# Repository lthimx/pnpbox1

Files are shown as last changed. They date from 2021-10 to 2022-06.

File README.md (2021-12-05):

<p align="center">
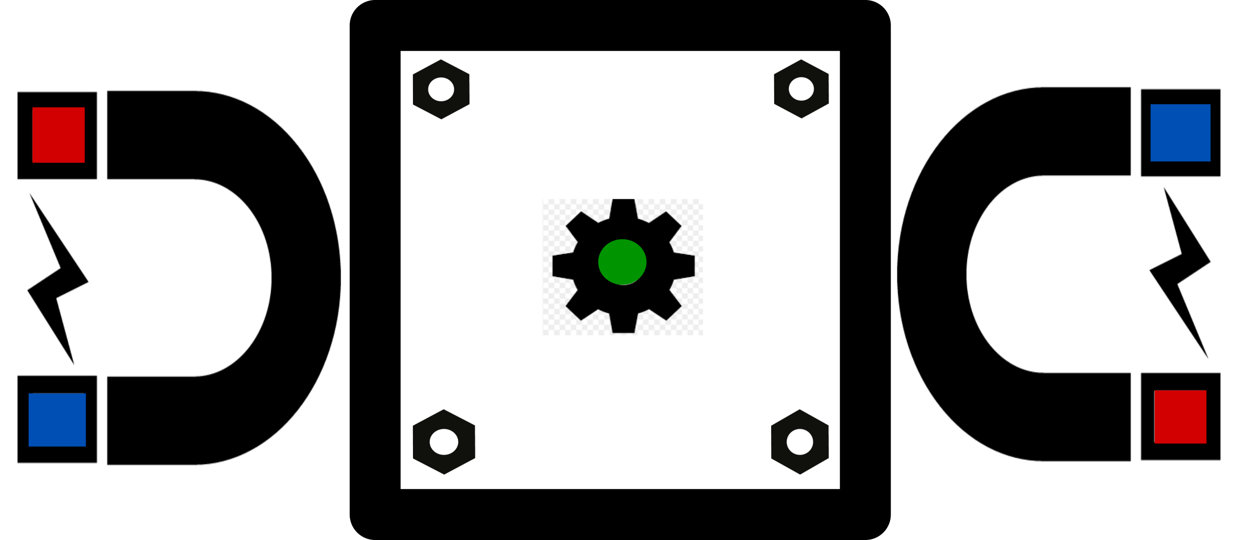
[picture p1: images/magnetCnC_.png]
MagnetCnC 3 logo
 
</p>
<h1 align="center">MagnetCnC 3</h1>

This is a prototype for pick and place, smd soldering but also laser cutting/engraving.
The head and the moving arm of the prototype will be design to be modular and magnetic (No screwing is neeeded to change/upgrade the head or arm).

## Visual overview
This is a visual overview of what the prototype does... for the moment, because it will does more "usecool" things like soldering and laser engraving or cutting.

pnpbox1

## Global view of the prototype

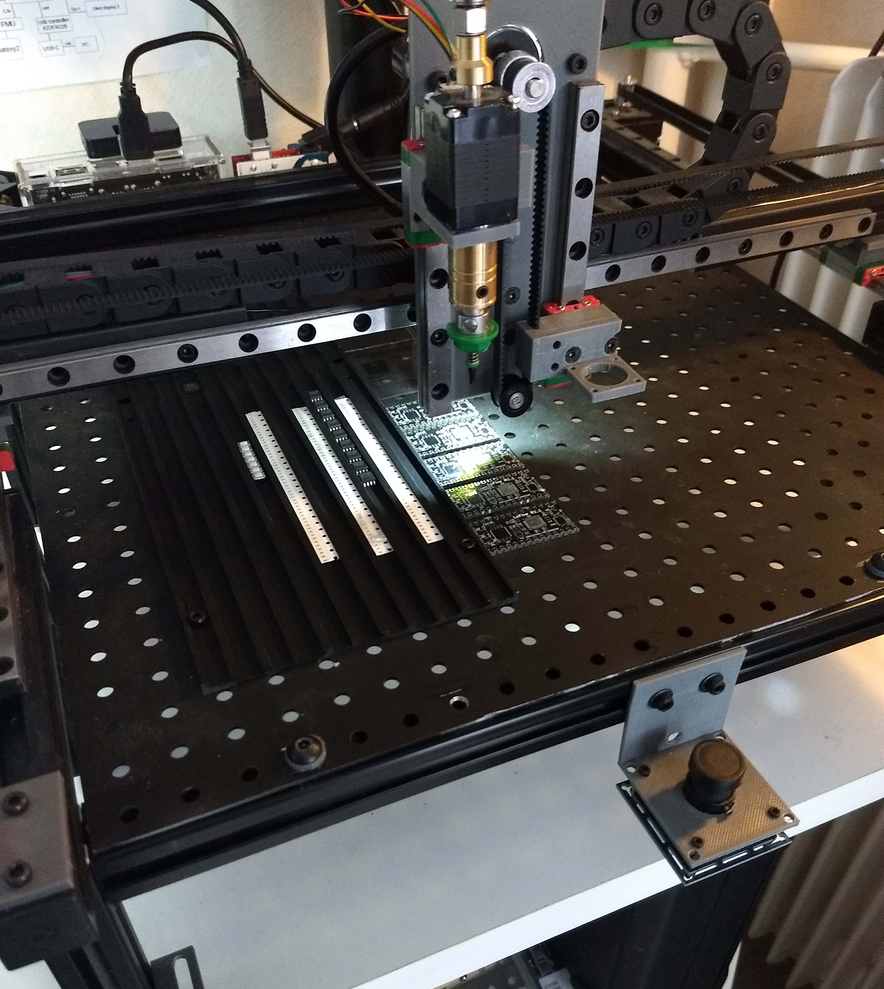
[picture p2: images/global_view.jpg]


## Buttons
This is a view of two buttons for reset and unlock operations but it can be re-configured for others actions.

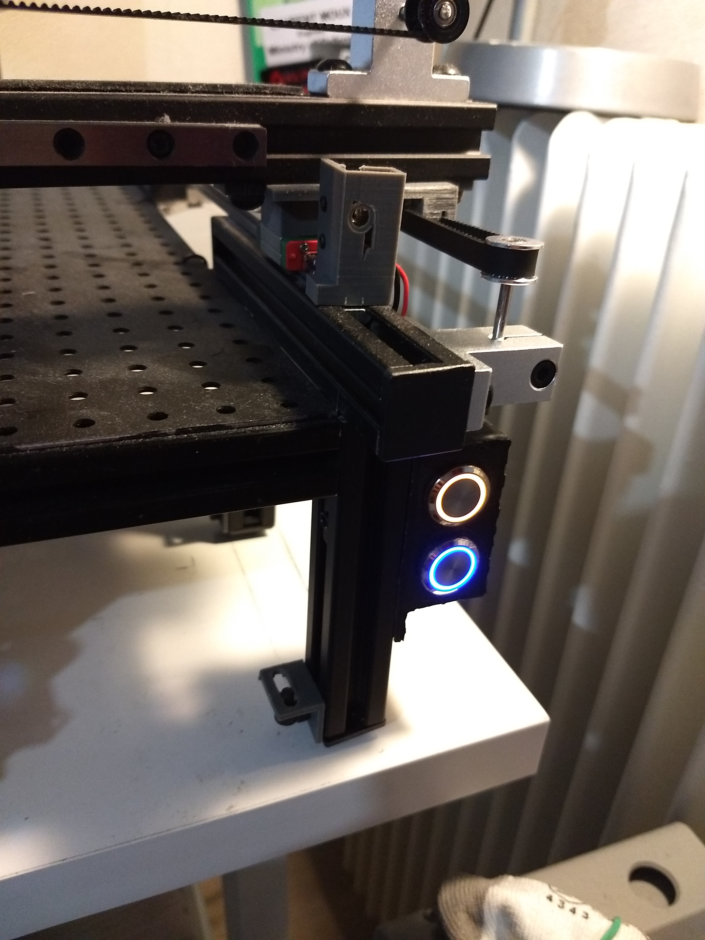
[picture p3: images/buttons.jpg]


## Pnpbox1 
This is an overview of the prototype box which contains all the mains components, the pump too ! .

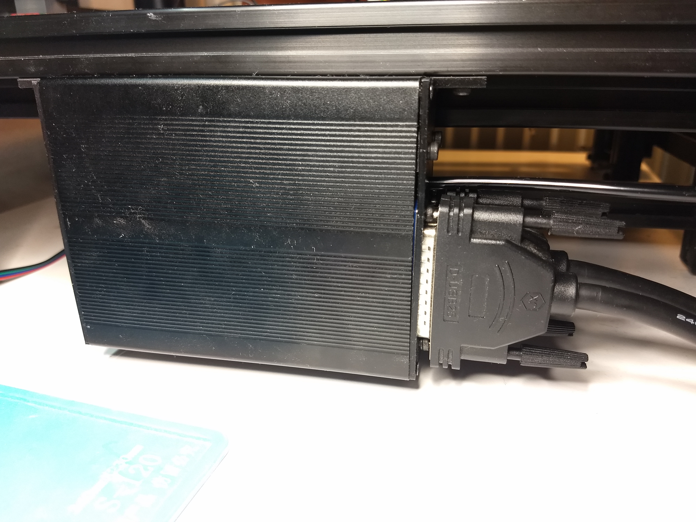
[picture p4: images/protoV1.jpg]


## DB25 pinout
This is the pinout of the two DB25 connectors on the Pnpbox
<p align="center">
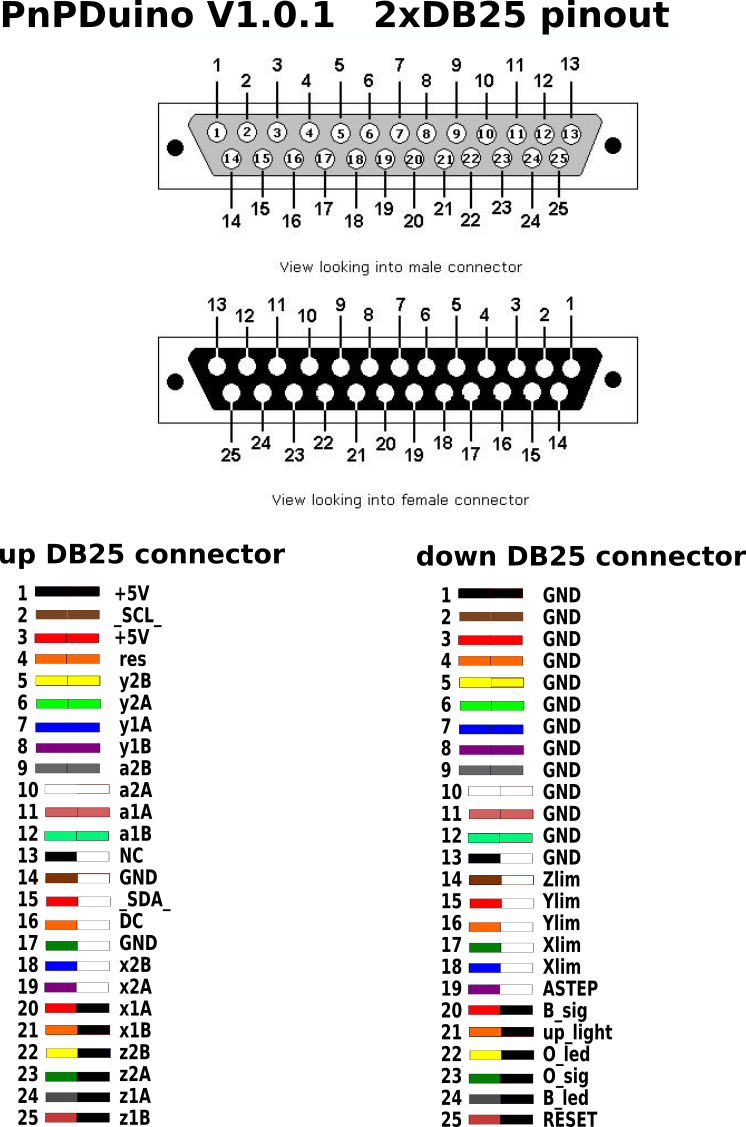
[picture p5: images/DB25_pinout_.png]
DB25 pinout
  
</p>

## Inside the pnpboxV1.0.1 prototype: Global view
<p align="center">
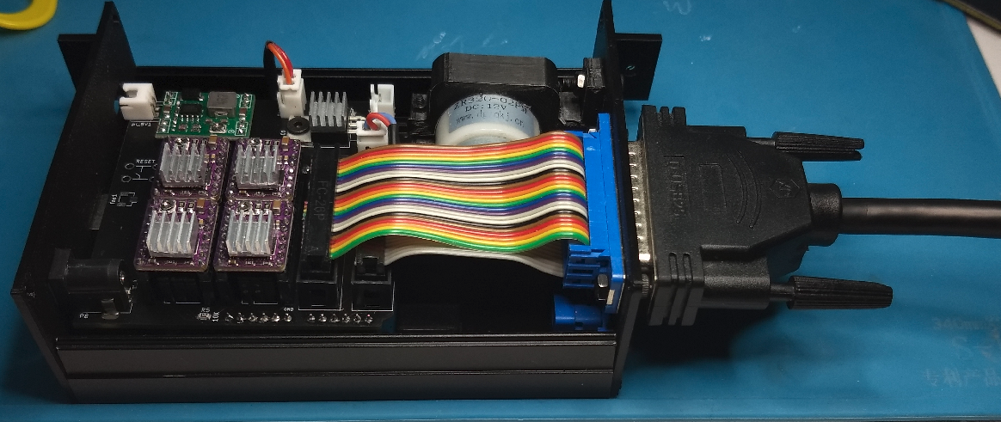
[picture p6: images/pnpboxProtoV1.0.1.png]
pnpBoxProtoV1.0.1
  
</p>

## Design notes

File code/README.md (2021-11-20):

# Programming
Here are codes for the machine movements management.
Arduino program will be adapted for the severals needs of the prototype then it will be ported on hifive rev b RISC-V board.

In order to understand how to program a stepper motor, here is a useful link from [Makerguides](https://www.makerguides.com/a4988-stepp$er-motor-driver-arduino-tutorial/)

## Zephyr OS
[Zephyr OS](https://zephyrproject.org/) will be used for the hifive rev b board because it is based on a small-footprint kernel designed for resource-constrained and embedded systems. Moreover it is open source and it is a project supported by the zephyr community.[Here](https://docs.zephyrproject.org/latest/getting_started/index.html) is the Zephyr getting started guide.

## List of main.c functions to be ported on hifive rev b

|Functions|Description|status|
|:---: | :---: |:---:|
|serial_init()| Setup serial baud rate and interrupt| OK| 
|setting_init()| Load grbl settings from flash memory| in progress|
|stepper_init()| Configure stepper pins and interrupt timers|in progress|
|system_init()| Configure pinout pins and pin-change interrupt|in progress|
|sei()| Enable interrupts| in progress|
|serial_reset_read_buffer()| Clear serial read buffer| in progress|
|gc_init()| set g-code parser to default state| in progress|
|pump_init()| init pump| in progress|
|rst_led_init()| init reset button | in progress |
|limits_init()| init limit pin| in progress|
|...|...|...|

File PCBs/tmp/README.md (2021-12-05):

# DuinoPnP v1
Here are the kicad files for the prototype shield for the machine, it is designed with the arduino-uno form factor, i call it the "duinoPnP"

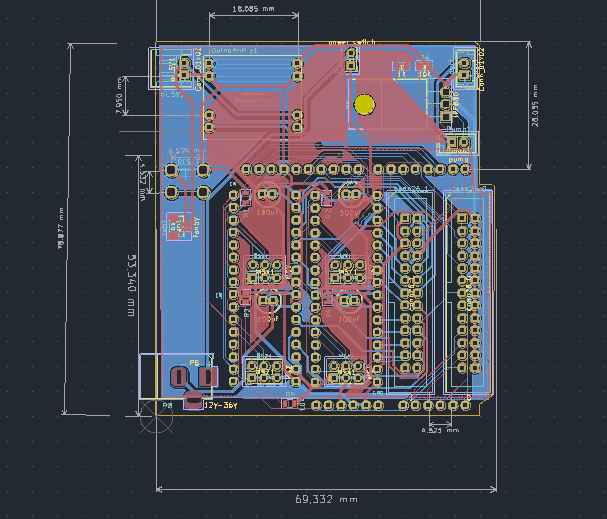
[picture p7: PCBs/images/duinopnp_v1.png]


## v1.0.1 3D viewer

Global 3D view of V1.0.1 PCB
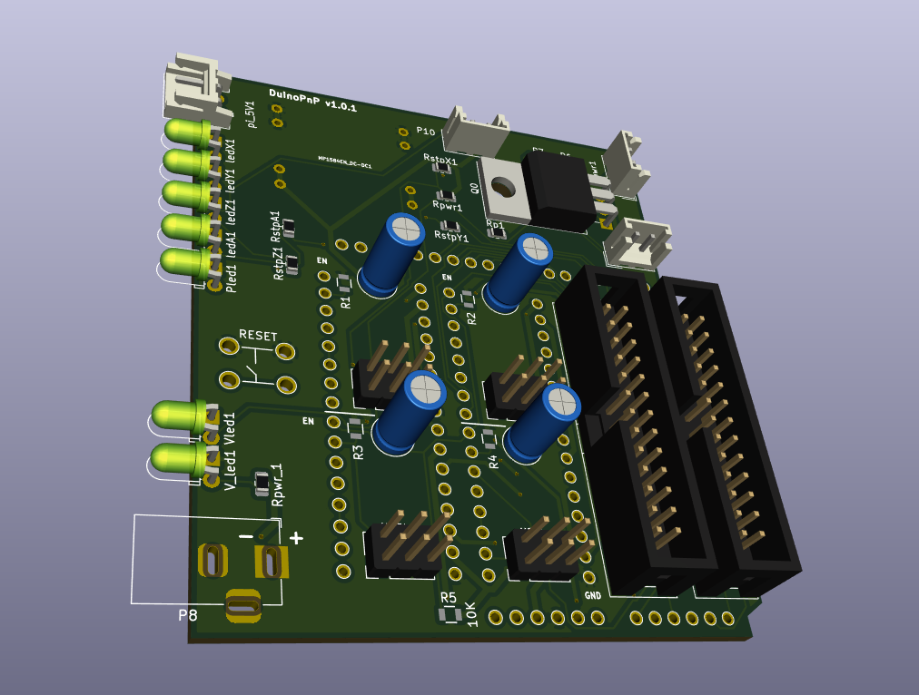
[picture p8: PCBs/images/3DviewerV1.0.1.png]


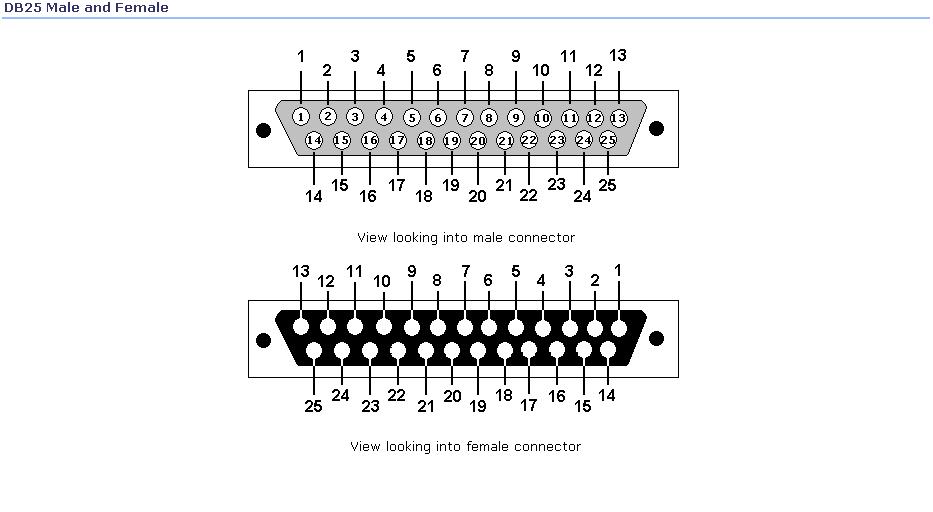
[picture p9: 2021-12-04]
images/Db25_pinout.jpg

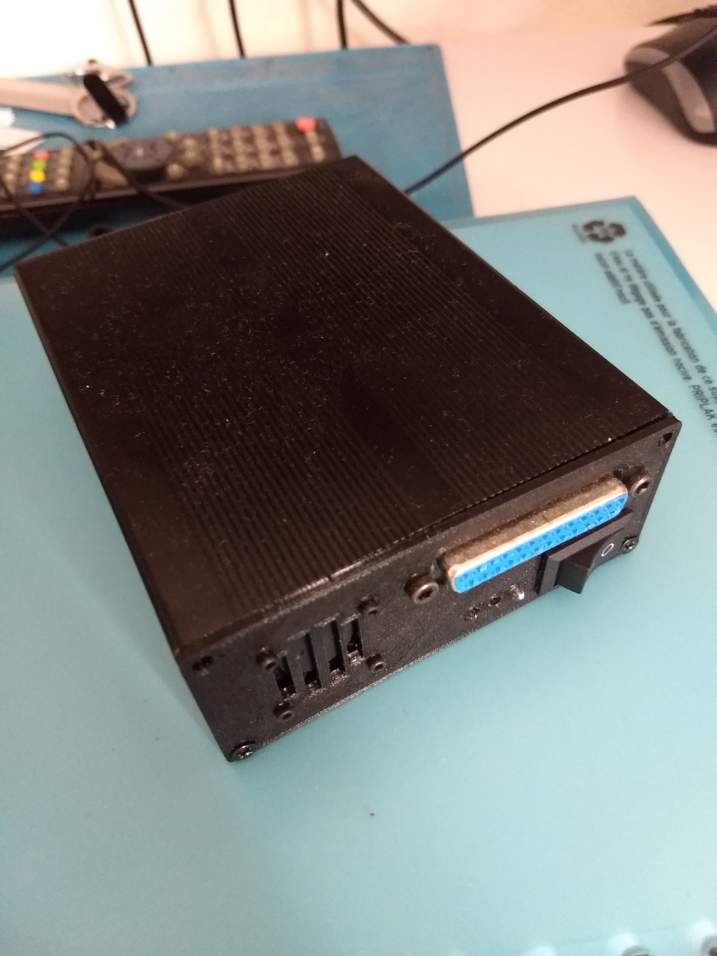
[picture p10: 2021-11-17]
images/pnpbox1.jpg

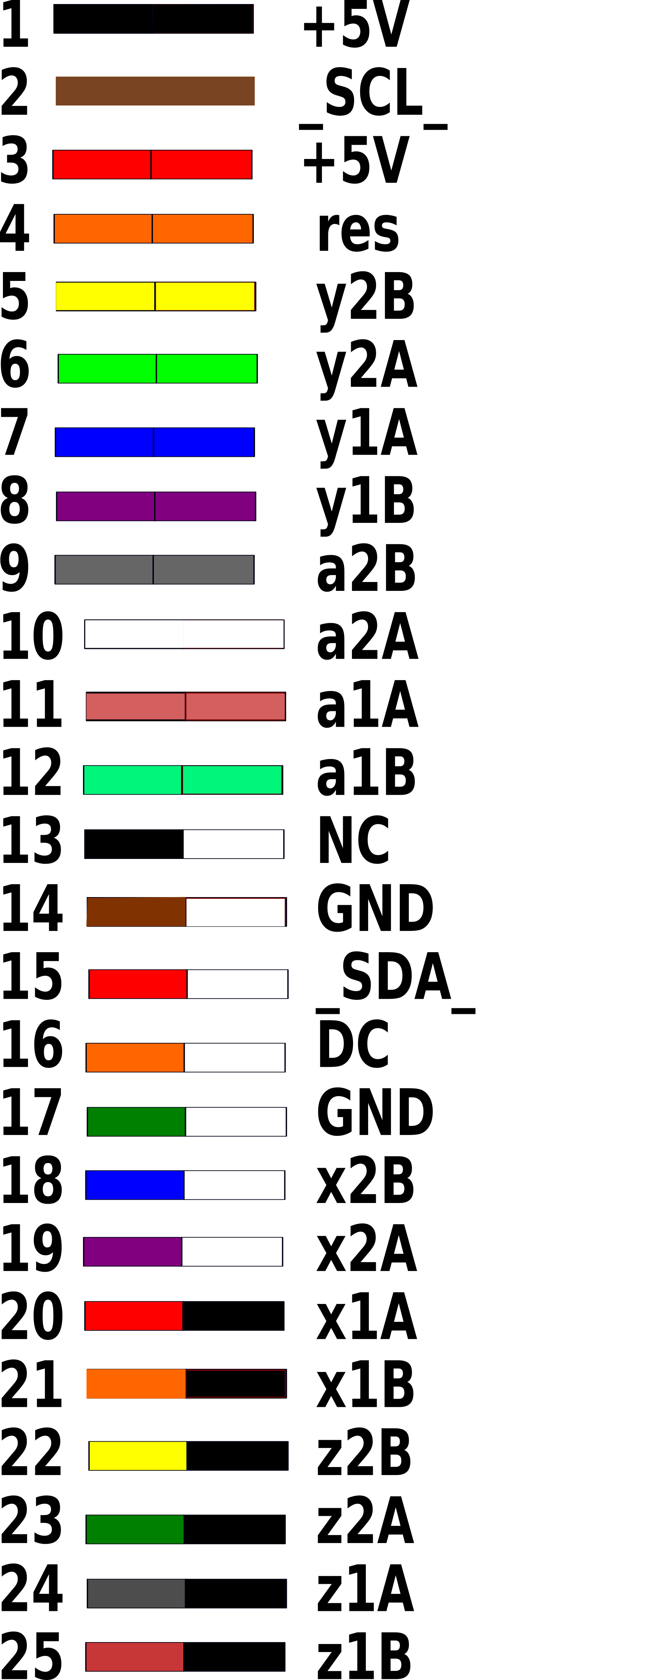
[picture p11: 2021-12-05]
images/text990.png

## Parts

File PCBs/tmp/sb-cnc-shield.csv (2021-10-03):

Reference | Value | Footprint | Datasheet
U1 | ARDUINO_UNO_SHIELD | footprints:ARDUINO_SHIELD
U5 | A | footprints:POLOLU_STEPPER_DRIVER
U3 | Y | footprints:POLOLU_STEPPER_DRIVER
U2 | X | footprints:POLOLU_STEPPER_DRIVER
U4 | Z | footprints:POLOLU_STEPPER_DRIVER
P1 | XMOT | Pin_Headers:Pin_Header_Straight_2x04
P2 | YMOT | Pin_Headers:Pin_Header_Straight_2x04
P3 | ZMOT | Pin_Headers:Pin_Header_Straight_2x04
P4 | AMOT | Pin_Headers:Pin_Header_Straight_2x04
JP1 | Jumper_NO_Small | footprints:Pin_100mil_Header_Straight_1x02
JP2 | Jumper_NO_Small | footprints:Pin_100mil_Header_Straight_1x02
JP3 | Jumper_NO_Small | footprints:Pin_100mil_Header_Straight_1x02
R1 | 100K | Resistors_SMD:R_0805
R2 | 100K | Resistors_SMD:R_0805
JP4 | Jumper_NO_Small | footprints:Pin_100mil_Header_Straight_1x02
JP5 | Jumper_NO_Small | footprints:Pin_100mil_Header_Straight_1x02
JP6 | Jumper_NO_Small | footprints:Pin_100mil_Header_Straight_1x02
JP7 | Jumper_NO_Small | footprints:Pin_100mil_Header_Straight_1x02
JP8 | Jumper_NO_Small | footprints:Pin_100mil_Header_Straight_1x02
JP9 | Jumper_NO_Small | footprints:Pin_100mil_Header_Straight_1x02
R3 | 100K | Resistors_SMD:R_0805
JP10 | Jumper_NO_Small | footprints:Pin_100mil_Header_Straight_1x02
JP11 | Jumper_NO_Small | footprints:Pin_100mil_Header_Straight_1x02
JP12 | Jumper_NO_Small | footprints:Pin_100mil_Header_Straight_1x02
R4 | 100K | Resistors_SMD:R_0805
C1 | 100uF | Capacitors_SMD:c_elec_6.3x7.7
C2 | 100uF | Capacitors_SMD:c_elec_6.3x7.7
C3 | 100uF | Capacitors_SMD:c_elec_6.3x7.7
C4 | 100uF | Capacitors_SMD:c_elec_6.3x7.7
P5 | UART | Pin_Headers:Pin_Header_Straight_1x04
P6 | I2C | Pin_Headers:Pin_Header_Straight_1x04
JP13 | Z+ | footprints:Pin_100mil_Header_Straight_1x02
JP14 | Z- | footprints:Pin_100mil_Header_Straight_1x02
JP15 | Y+ | footprints:Pin_100mil_Header_Straight_1x02
JP16 | Y- | footprints:Pin_100mil_Header_Straight_1x02
JP17 | X+ | footprints:Pin_100mil_Header_Straight_1x02
JP18 | X- | footprints:Pin_100mil_Header_Straight_1x02
JP19 | SpinEn | footprints:Pin_100mil_Header_Straight_1x02
JP20 | SpinDir | footprints:Pin_100mil_Header_Straight_1x02
JP21 | CoolEn | footprints:Pin_100mil_Header_Straight_1x02
JP22 | Abort | footprints:Pin_100mil_Header_Straight_1x02
JP23 | Hold | footprints:Pin_100mil_Header_Straight_1x02
JP24 | Resume | footprints:Pin_100mil_Header_Straight_1x02
P7 | ES_SETUP | Pin_Headers:Pin_Header_Straight_1x03
SW1 | RESET | footprints:SWITCH_TACTILE_6.5_PTH
JP25 | ESTOP | footprints:Pin_100mil_Header_Straight_1x02
JP26 | EN/GND | footprints:Pin_100mil_Header_Straight_1x02
JP27 | XSTEP/DIR | footprints:Pin_100mil_Header_Straight_1x02
JP28 | YSTEP/DIR | footprints:Pin_100mil_Header_Straight_1x02
JP29 | ZSTEP/DIR | footprints:Pin_100mil_Header_Straight_1x02
JP30 | ASTEP/DIR | footprints:Pin_100mil_Header_Straight_1x02
JP31 | +5V/GND | footprints:Pin_100mil_Header_Straight_1x02
JP32 | Jumper_NO_Small | footprints:Pin_100mil_Header_Straight_1x02
JP33 | Jumper_NO_Small | footprints:Pin_100mil_Header_Straight_1x02
JP34 | Jumper_NO_Small | footprints:Pin_100mil_Header_Straight_1x02
JP35 | Jumper_NO_Small | footprints:Pin_100mil_Header_Straight_1x02
JP36 | Jumper_NO_Small | footprints:Pin_100mil_Header_Straight_1x02
JP37 | Jumper_NO_Small | footprints:Pin_100mil_Header_Straight_1x02
JP38 | Jumper_NO_Small | footprints:Pin_100mil_Header_Straight_1x02
JP39 | Jumper_NO_Small | footprints:Pin_100mil_Header_Straight_1x02
P8 | 12V-36V | footprints:CONN_01x02_PITCH_5.08mm
R5 | 10K | Resistors_SMD:R_0805

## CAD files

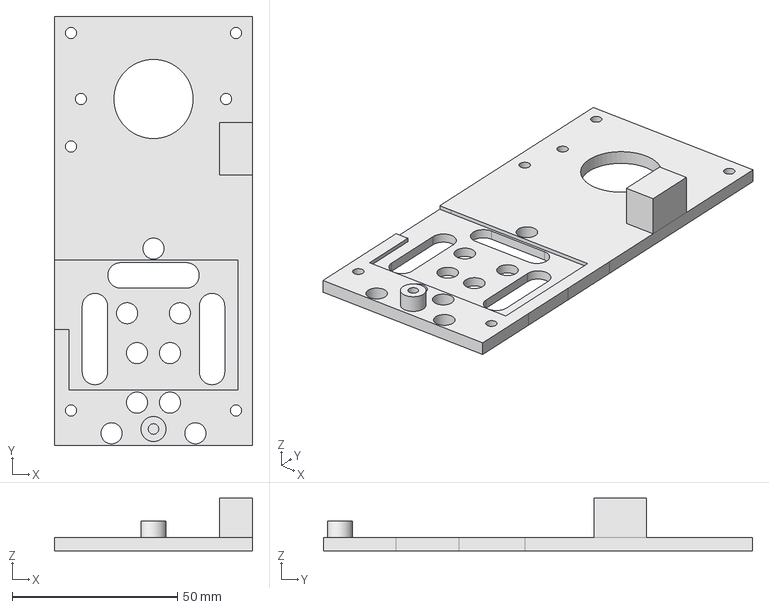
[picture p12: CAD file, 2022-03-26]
freecad/simplePnP/main_head_PnP_v1.02.FCStd
60.0 x 130.0 x 16.0 mm

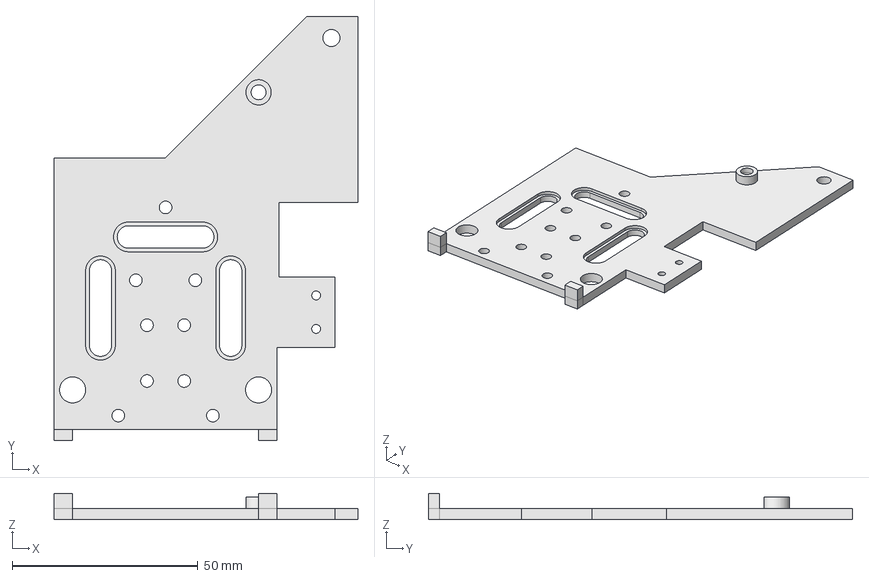
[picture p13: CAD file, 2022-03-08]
freecad/simplePnP/main_head_v1.01.FCStd
81.7 x 114.0 x 7.00 mm

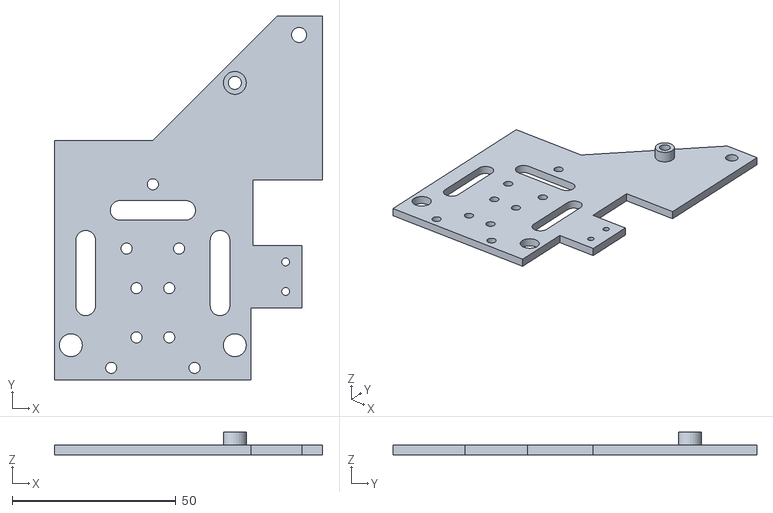
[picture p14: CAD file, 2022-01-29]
freecad/simplePnP/main_head_v1.03_with_pneumatic_cable_adapter.obj
81.7 x 111.0 x 7.00

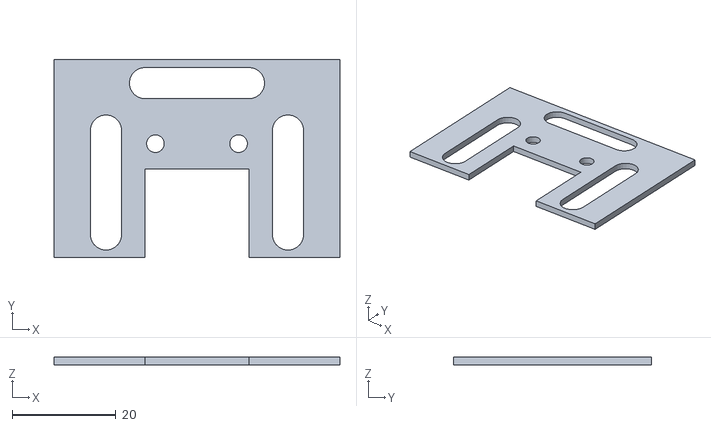
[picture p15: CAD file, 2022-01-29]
freecad/simplePnP/magnet_support_main_fixed_1.01.obj
55.0 x 38.0 x 1.50

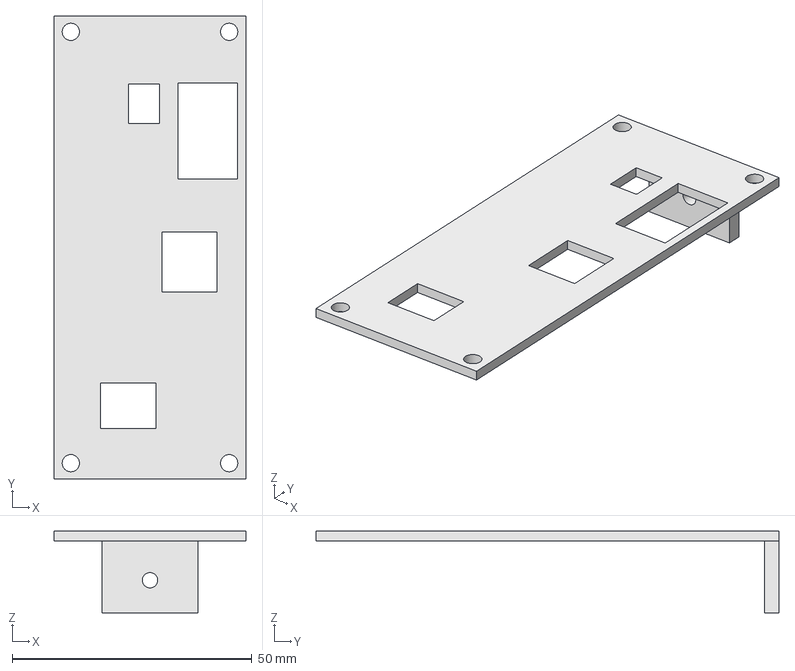
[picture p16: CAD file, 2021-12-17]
freecad/case_pnp/right_case_2.FCStd
40.0 x 96.5 x 17.0 mm

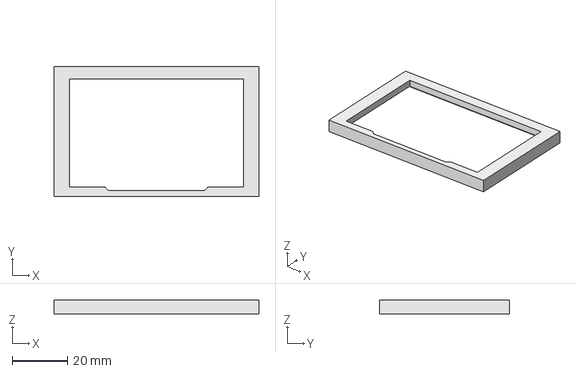
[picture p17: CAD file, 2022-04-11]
freecad/display/up_case.FCStd
74.1 x 47.0 x 5.00 mm

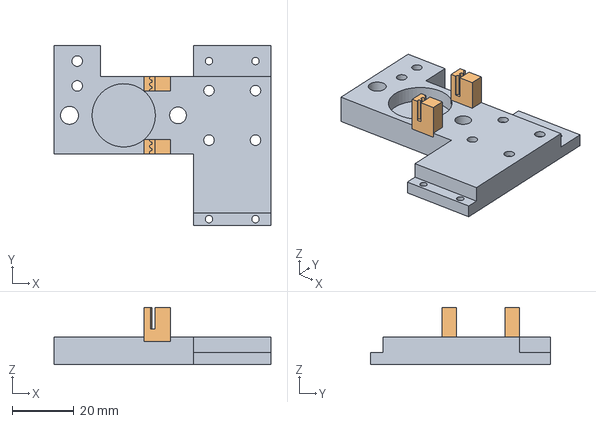
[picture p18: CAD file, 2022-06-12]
freecad/magnet_support_main_arm/down_left_magnet_arm.FCStd
70.0 x 58.0 x 18.5 mm
belt_support_left001

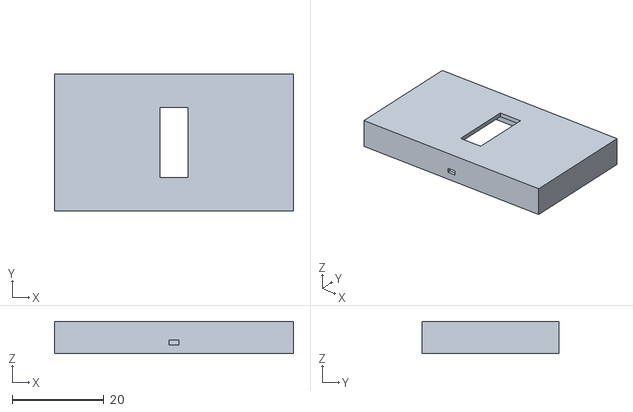
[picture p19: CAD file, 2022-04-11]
freecad/reset_button/reset_button_cache.obj
52.1 x 29.9 x 7.00

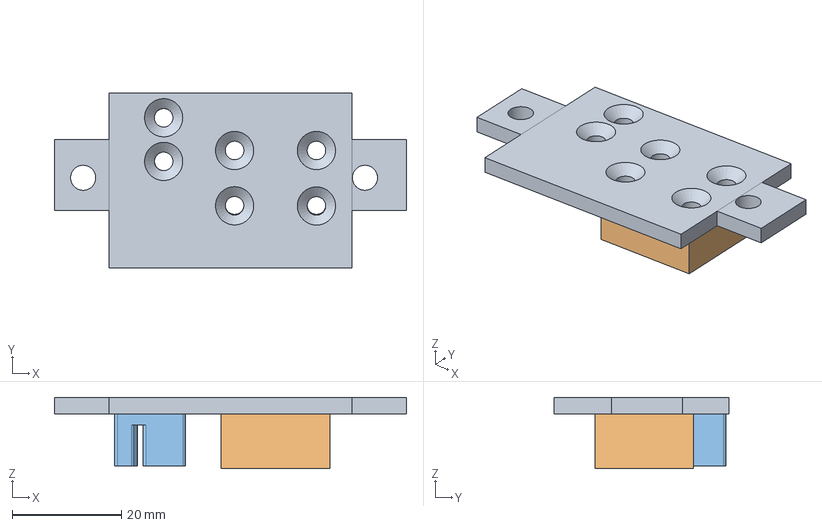
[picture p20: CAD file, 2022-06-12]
freecad/simplePnP/support_advanced_left.FCStd
64.5 x 32.0 x 13.0 mm

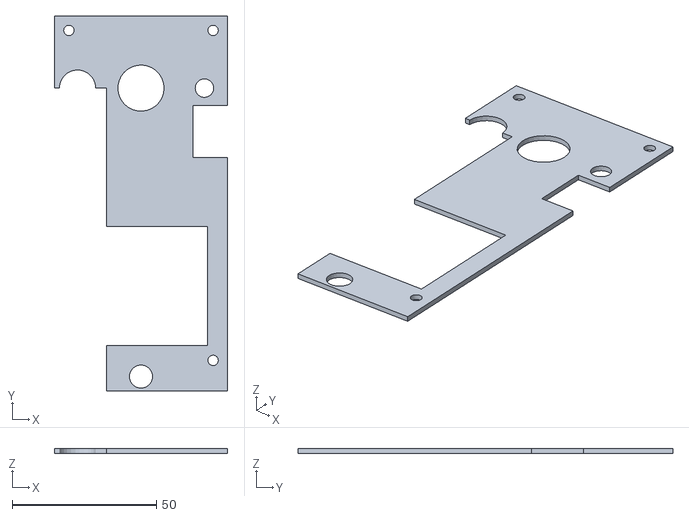
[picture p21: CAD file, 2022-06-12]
freecad/stl/head_pnp_1.stl
60.0 x 130.0 x 1.60

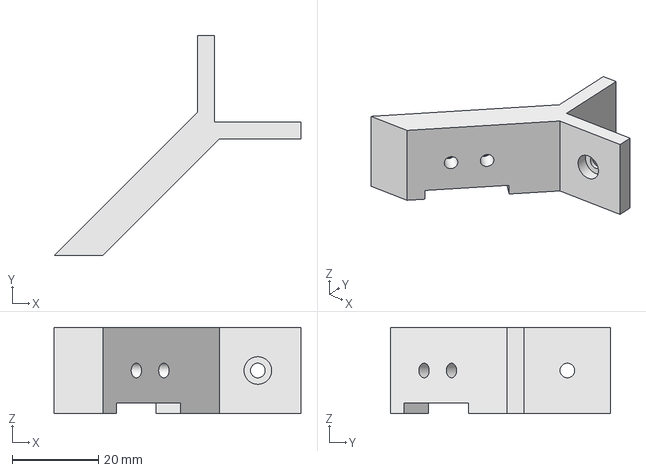
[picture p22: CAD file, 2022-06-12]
freecad/support_display/support_display.FCStd
57.2 x 51.0 x 20.0 mm

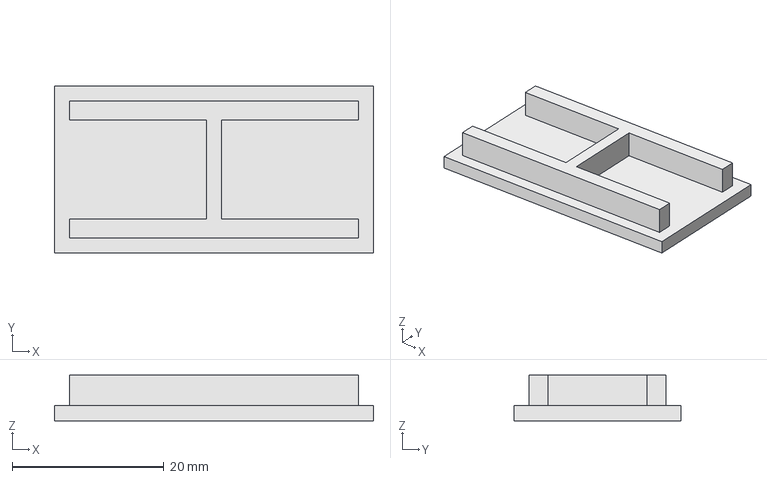
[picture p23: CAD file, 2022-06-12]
freecad/usb_cam_case/usb_down_case.FCStd
42.0 x 22.0 x 6.00 mm

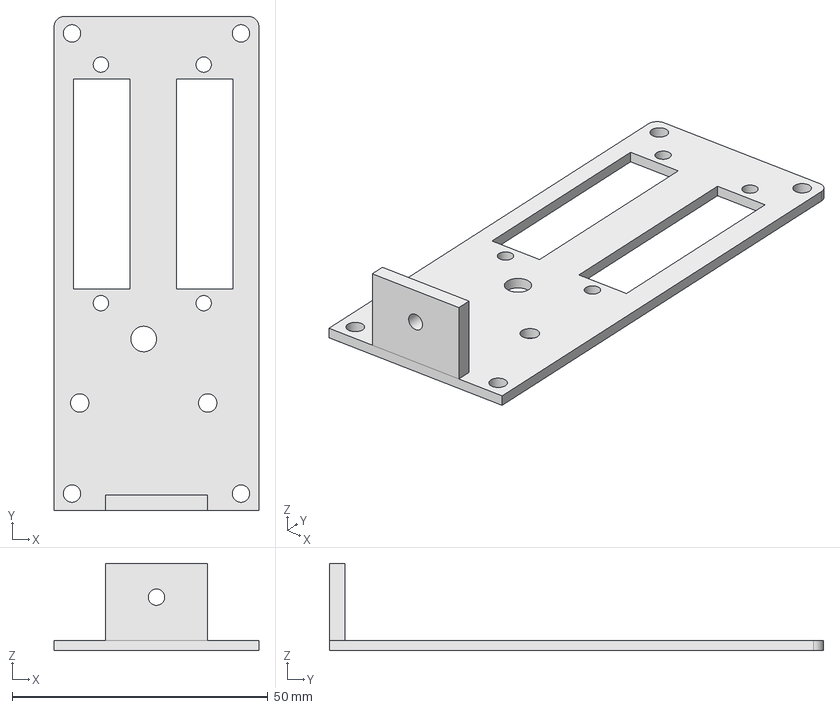
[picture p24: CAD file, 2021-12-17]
freecad/case_pnp/left_case_2.FCStd
40.0 x 96.5 x 17.0 mm

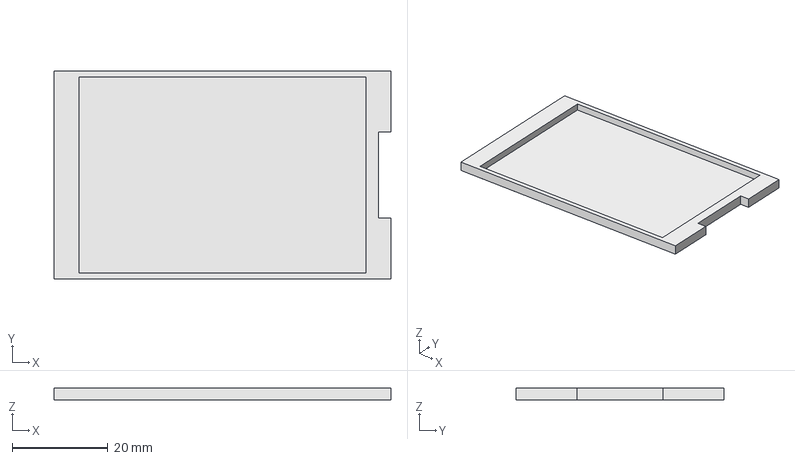
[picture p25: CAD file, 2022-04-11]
freecad/display/down_case.FCStd
70.5 x 43.6 x 2.50 mm

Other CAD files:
freecad/simplePnP/main_head_PnP_v1.01_4_tmp.FCStd
freecad/simplePnP/main_head_v1.03_with_pneumatic_cable_adapter_2.obj
freecad/magnet_support_main_arm/down_right_magnet_support_angle_arm.obj
freecad/reset_button/reset_unlock.obj
freecad/case_pnp/bute_arduino.FCStd
freecad/case_pnp/bute_arduino.obj
freecad/case_pnp/cale_arduino.obj
freecad/case_pnp/hifive_support.FCStd
freecad/case_pnp/left_case.FCStd
freecad/case_pnp/left_case_2_motore_conn.FCStd
freecad/case_pnp/pnp_case_left.obj
freecad/case_pnp/pnp_case_left_2.obj
freecad/case_pnp/pnp_case_left_motor_conn.obj
freecad/case_pnp/pnp_case_left_test.obj
freecad/case_pnp/pnp_case_right.obj
freecad/case_pnp/pnp_case_right_2.obj
freecad/case_pnp/pnp_support_hifive.obj
freecad/case_pnp/pump_support.FCStd
freecad/case_pnp/pump_supportV2.FCStd
freecad/case_pnp/right_case.FCStd
freecad/case_pnp/support_pump.obj
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

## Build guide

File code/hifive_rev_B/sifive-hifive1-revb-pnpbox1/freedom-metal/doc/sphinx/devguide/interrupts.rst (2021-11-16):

Interrupt Handlers
==================

The Interrupt Heirarchy
-----------------------

Freedom Metal conceptualizes interrupts as a heirarchy of interrupt controllers.
This heirarchy is established by the interrupt heirarchy of the target platform
itself. Presently, the interrupt heirarchy for a given platform is best documented
by the target's DeviceTree representation, which can be found in
``bsp/<target-name>/design.dts``.

In Freedom Metal, the heirarchy is a tree. The nodes of the tree consist of
``struct metal_interrupt``:

.. doxygenstruct:: metal_interrupt
   :project: metal

And the vertices of the tree consist of interrupt ``id``.

.. digraph:: int_heirarchy_graph

   cpu [label="CPU"];
   cpu_int [label="CPU Interrupt Controller", shape=box];
   timer_int [label="Timer Interrupt Controller", shape=box];
   soft_int [label="Software Interrupt Controller", shape=box];

   cpu -> cpu_int [label="ID = 0"];
   cpu_int -> timer_int [label="ID = timer_id"];
   cpu_int -> soft_int [label="ID = software_id"];

The CPU Interrupt Controller
----------------------------

The CPU interrupt controller is the top of the interrupt heirarchy. It must be
initialized before any other interrupt controllers are initialized. In example:

.. code-block:: C

   struct metal_cpu *cpu0 = metal_cpu_get(0);
   if(!cpu) {
      /* Unable to get CPU handle */
   }
   struct metal_interrupt *cpu_int = metal_cpu_interrupt_controller(cpu0);
   if(!cpu_int) {
      /* Unable to get CPU interrupt handle */
   }
   metal_interrupt_init(cpu_int);

The CPU interrupt must be enabled for the CPU to receive any interrupts, and any
enabled interrupts can be masked by disabling the CPU interrupt.

.. code-block:: C

   int rc = 0;

   /* Enable the CPU interrupt */
   rc = metal_interrupt_enable(cpu_int, 0);
   if(rc != 0) {
      /* Failed to enable the CPU interrupt */
   }

   /* Disable the CPU interrupt */
   rc = metal_interrupt_disable(cpu_int, 0);
   if(rc != 0) {
      /* Failed to disable the CPU interrupt */
   }

Interrupt Handlers
------------------

Interrupt handlers must conform to the following function signature:

.. doxygentypedef:: metal_interrupt_handler_t
   :project: metal

Therefore, an interrupt handler might look like:

.. code-block:: C

   void my_interrupt_handler(int id, void *priv_data) {
      /* Contents of handler */
   }

Registering an Interrupt Handler
--------------------------------

Interrupt handlers are registered with the interrupt controller for the interrupt
they are servicing. For example, if we want to register a CPU timer interrupt:

.. code-block:: C

   struct metal_interrupt *timer_int = metal_cpu_timer_interrupt_controller(cpu0);
   if(!timer_int) {
      /* Failed to get timer interrupt controller */
   }
   metal_interrupt_init(timer_int);

   int timer_id = metal_cpu_timer_get_interrupt_id(cpu0);

   int rc = metal_interrupt_register_handler(timer_int, timer_id, my_interrupt_handler, cpu0);
   if(rc != 0) {
      /* Failed to register interrupt handler */
   }

Additional Documentation
------------------------

Additional documentation for the interrupt handler API can be found in
:doc:`the CPU API reference </apiref/cpu>` and
:doc:`the Interrupt API reference </apiref/interrupt>`.

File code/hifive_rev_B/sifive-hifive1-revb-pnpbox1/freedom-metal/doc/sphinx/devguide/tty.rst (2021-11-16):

Standard I/O
============

Freedom Metal integrates with libc ``STDOUT`` to provide virtual terminal support.
The default ``STDOUT`` device is the first UART serial peripheral on the target.
If no UART serial peripheral is present, such as in the case of SiFive CoreIP
test harnesses, then the bytes sent to ``STDOUT`` are dropped.

Hello World
-----------

Using the virtual terminal with Freedom Metal is exactly what you might expect:

.. code-block:: C
   :linenos:

   #include <stdio.h>

   int main(void) {
      printf("Hello, world!");

      return 0;
   }

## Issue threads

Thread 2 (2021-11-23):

Test the little FS in flash with Zephyr OS on the hifive1 revb

lthimx, 2021-11-23:
Hi,
When i lunch the command "west build -p auto -b hifive1_revb samples/subsys/nvs/" in order to compile the sample, i get this first error:

error: '__device_dts_ord_DT_COMPAT_fixed_partitions_LABEL_storage_PARENT_PARENT_ORD' undeclared (first use in this function)
   81 | #define DEVICE_NAME_GET(name) _CONCAT(__device_, name)
      |                                       ^~~~~~~~~

The __device_ parameter seems to be undeclared. I'm currently trying to debug the modules and susbsys contents to solve the problem...
Any idea on where i may focus on principally ?

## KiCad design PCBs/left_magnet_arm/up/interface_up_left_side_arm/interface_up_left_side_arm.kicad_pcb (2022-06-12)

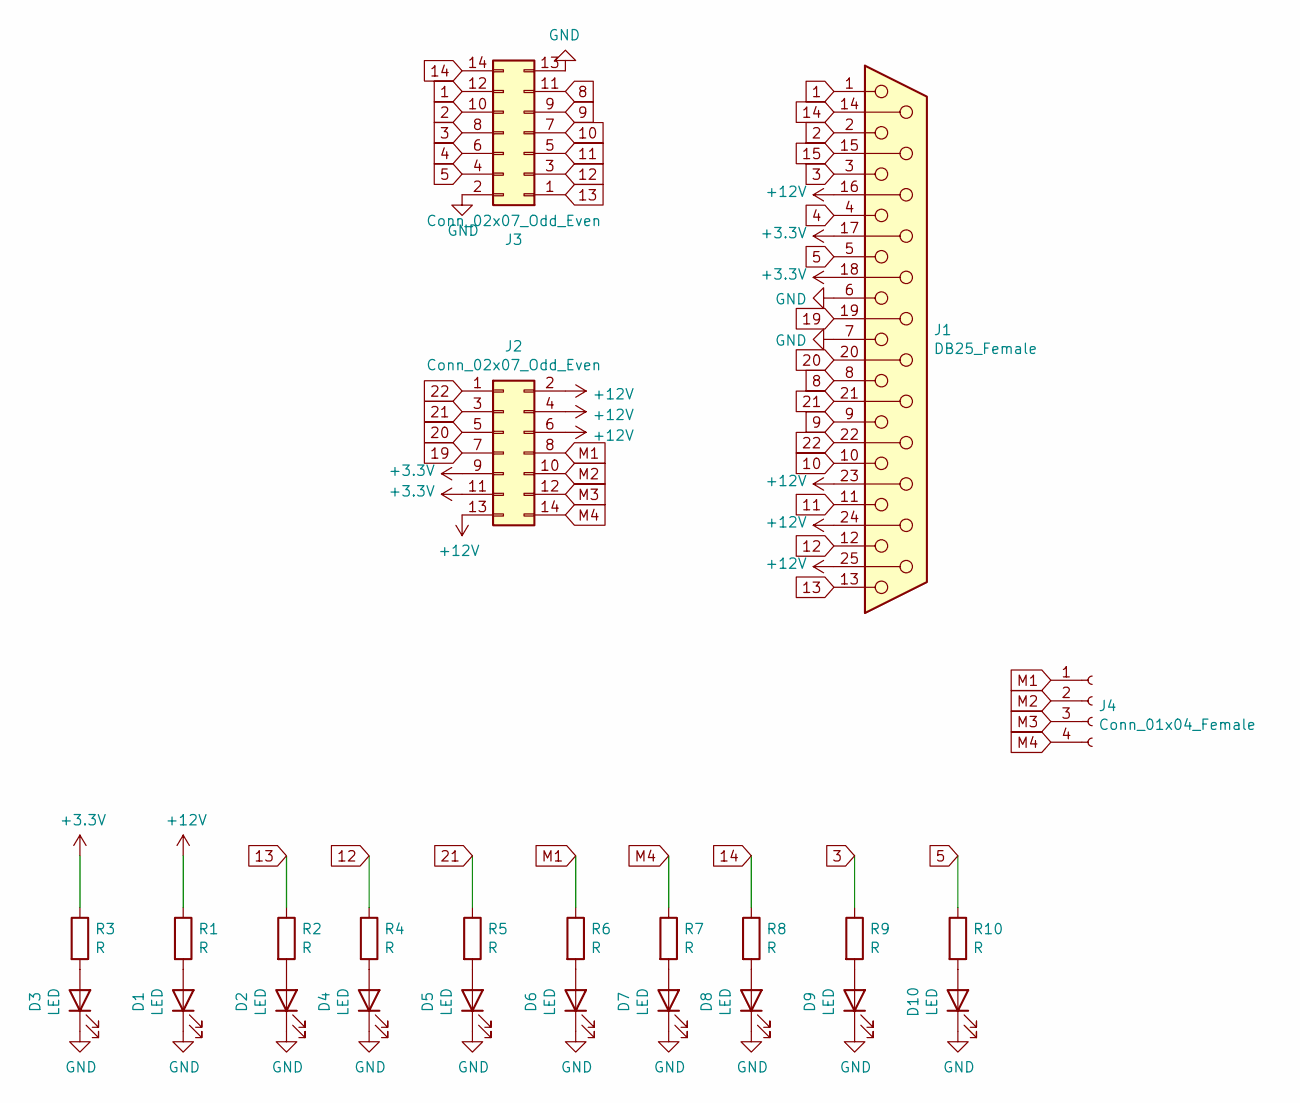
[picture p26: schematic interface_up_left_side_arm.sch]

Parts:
D1, D2, D3, D4, D5, D6, D7, D8, D9, D10: LED; LED_1206_3216Metric_Pad1.42x1.75mm_HandSolder
J1: DB25_Female; DSUB-25_Female_Vertical_P2.77x2.84mm_MountingHoles
J2, J3: Conn_02x07_Odd_Even; PinHeader_2x07_P2.54mm_Vertical
J4: Conn_01x04_Female; JST_EH_B4B-EH-A_1x04_P2.50mm_Vertical
R1, R2, R3, R4, R5, R6, R7, R8, R9, R10: R; R_0805_2012Metric

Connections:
1: J1.1, J3.12
2: J1.2, J3.10
3: J1.3, J3.8, R9.1
4: J1.4, J3.6
5: J1.5, J3.4, R10.1
8: J1.8, J3.11
9: J1.9, J3.9
10: J1.10, J3.7
11: J1.11, J3.5
12: J1.12, J3.3, R4.1
13: J1.13, J3.1, R2.1
14: J1.14, J3.14, R8.1
15: J1.15
19: J1.19, J2.7
20: J1.20, J2.5
21: J1.21, J2.3, R5.1
22: J1.22, J2.1
+3V3: J1.17, J1.18, J2.9, J2.11, R3.1
+12V: J1.16, J1.23, J1.24, J1.25, J2.2, J2.4, J2.6, J2.13, R1.1
GND: D1.1 (K), D2.1 (K), D3.1 (K), D4.1 (K), D5.1 (K), D6.1 (K), D7.1 (K), D8.1 (K), D9.1 (K), D10.1 (K), J1.6, J1.7, J3.2, J3.13
M1: J2.8, J4.1, R6.1
M2: J2.10, J4.2
M3: J2.12, J4.3
M4: J2.14, J4.4, R7.1
unnamed: D1.2 (A), R1.2
unnamed: D2.2 (A), R2.2
unnamed: D3.2 (A), R3.2
unnamed: D4.2 (A), R4.2
unnamed: D5.2 (A), R5.2
unnamed: D6.2 (A), R6.2
unnamed: D7.2 (A), R7.2
unnamed: D8.2 (A), R8.2
unnamed: D9.2 (A), R9.2
unnamed: D10.2 (A), R10.2

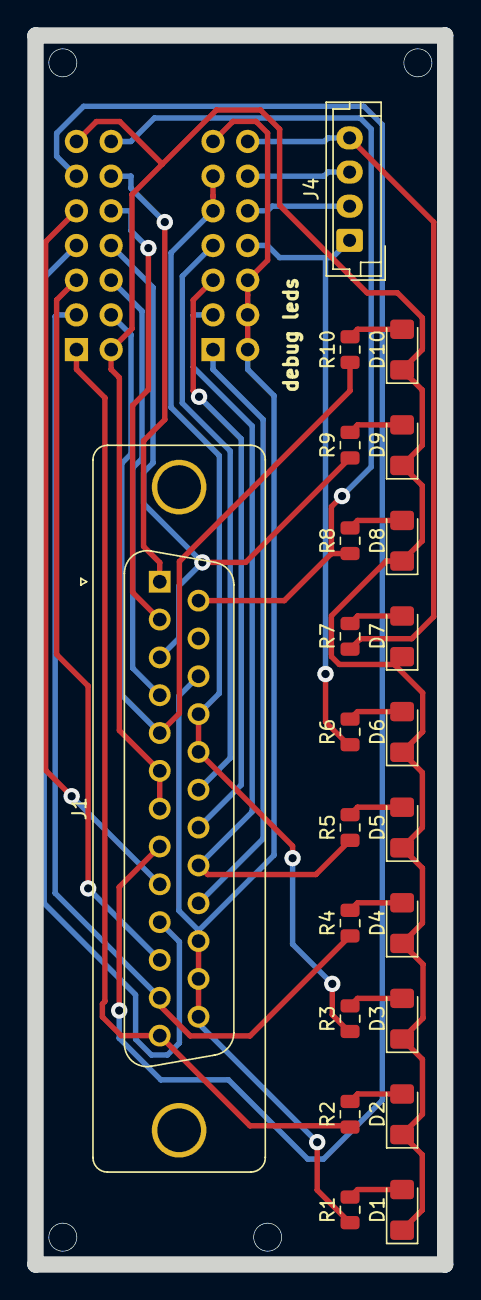
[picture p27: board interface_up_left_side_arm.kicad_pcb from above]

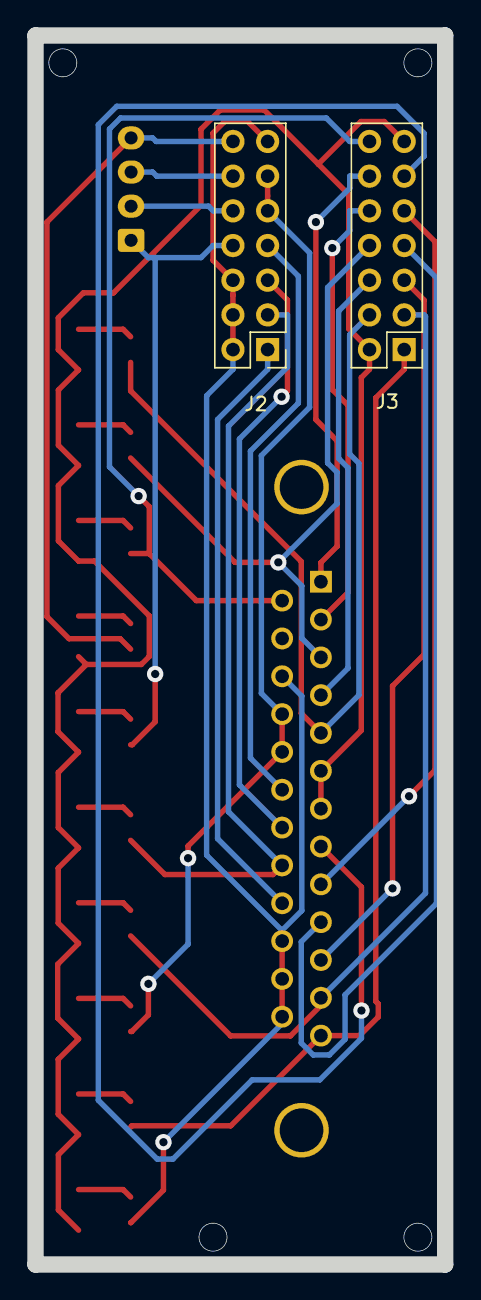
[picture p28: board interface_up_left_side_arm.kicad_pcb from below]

Board: 2 copper layers, 30.0 x 90.0 mm, 24 parts (2 on the bottom side), 33 nets.

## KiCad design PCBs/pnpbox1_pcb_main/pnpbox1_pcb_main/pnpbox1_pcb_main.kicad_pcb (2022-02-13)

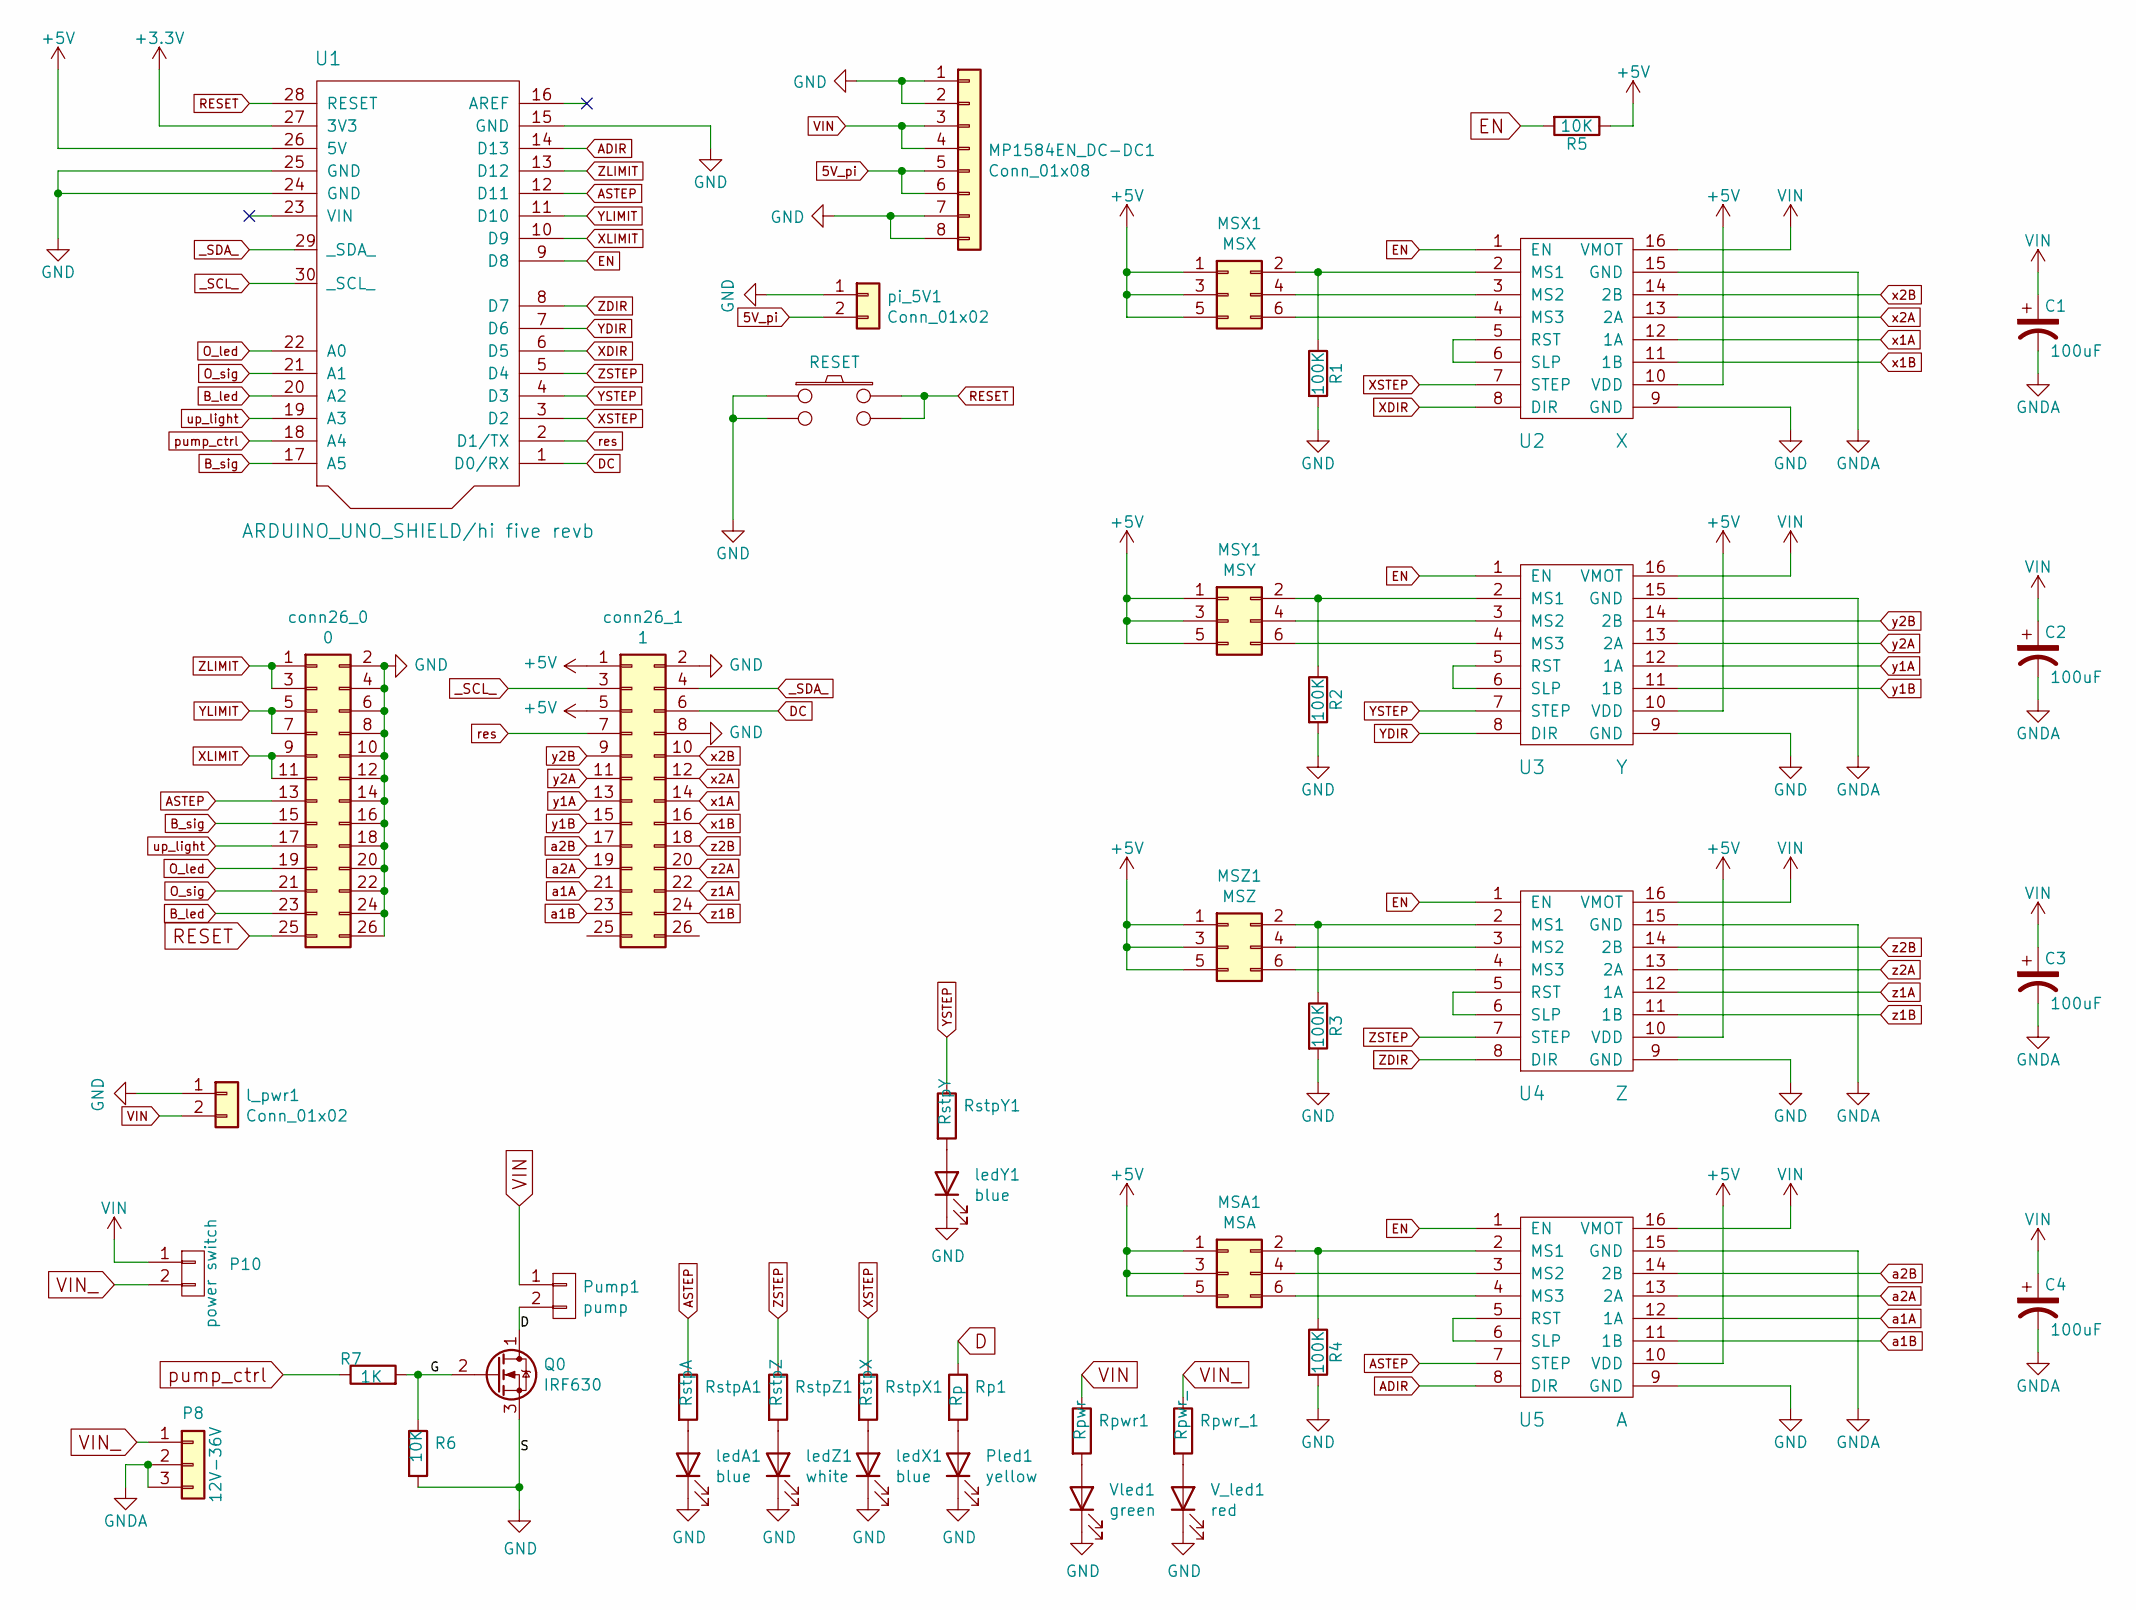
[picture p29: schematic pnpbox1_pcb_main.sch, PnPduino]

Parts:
C1, C2, C3, C4: 100uF; C_Radial_D5.0mm_H11.0mm_P2.00mm
MP1584EN_DC-DC1: Conn_01x08; MP1584EN convertisseur DC-DC
MSA1: MSA; PinHeader_2x03_P2.54mm_Vertical
MSX1: MSX; PinHeader_2x03_P2.54mm_Vertical
MSY1: MSY; PinHeader_2x03_P2.54mm_Vertical
MSZ1: MSZ; PinHeader_2x03_P2.54mm_Vertical
P8: 12V-36V; BarrelJack_Horizontal
P10: power switch; JST_EH_B2B-EH-A_1x02_P2.50mm_Vertical
Pled1: yellow; LED_D3.0mm_Horizontal_O1.27mm_Z2.0mm
Pump1: pump; JST_EH_B2B-EH-A_1x02_P2.50mm_Vertical
Q0: IRF630; TO-220-3_Horizontal_TabDown
R1, R2, R3, R4: 100K; R_0805
R5: 10K; R_0805
R6: 10K; R_0805_2012Metric
R7: 1K; R_0805_2012Metric
Rp1: Rp; R_0805_2012Metric
Rpwr1: Rpwr; R_0805_2012Metric
Rpwr_1: Rpwr_; R_0805_2012Metric
RstpA1: RstpA; R_0805_2012Metric
RstpX1: RstpX; R_0805_2012Metric
RstpY1: RstpY; R_0805_2012Metric
RstpZ1: RstpZ; R_0805_2012Metric
SW1: RESET; SWITCH_TACTILE_6.5_PTH
U1: ARDUINO_UNO_SHIELD/hi five revb; ARDUINO_SHIELD
U2: X; POLOLU_STEPPER_DRIVER
U3: Y; POLOLU_STEPPER_DRIVER
U4: Z; POLOLU_STEPPER_DRIVER
U5: A; POLOLU_STEPPER_DRIVER
V_led1: red; LED_D3.0mm_Horizontal_O1.27mm_Z2.0mm
Vled1: green; LED_D3.0mm_Horizontal_O1.27mm_Z2.0mm
conn26_0: 0; IDC-Header_2x13_P2.54mm_Vertical
conn26_1: 1; IDC-Header_2x13_P2.54mm_Vertical
l_pwr1: Conn_01x02; JST_EH_B2B-EH-A_1x02_P2.50mm_Vertical
ledA1: blue; LED_D3.0mm_Horizontal_O1.27mm_Z2.0mm
ledX1: blue; LED_D3.0mm_Horizontal_O1.27mm_Z2.0mm
ledY1: blue; LED_D3.0mm_Horizontal_O1.27mm_Z2.0mm
ledZ1: white; LED_D3.0mm_Horizontal_O1.27mm_Z2.0mm
pi_5V1: Conn_01x02; JST_EH_S2B-EH_1x02_P2.50mm_Horizontal

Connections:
5V_pi: MP1584EN_DC-DC1.5, MP1584EN_DC-DC1.6, pi_5V1.2
+3V3: U1.27 (3V3)
+5V: MSA1.1, MSA1.3, MSA1.5, MSX1.1, MSX1.3, MSX1.5, MSY1.1, MSY1.3, MSY1.5, MSZ1.1, MSZ1.3, MSZ1.5, R5.1, U1.26 (5V), U2.10 (VDD), U3.10 (VDD), U4.10 (VDD), U5.10 (VDD), conn26_1.1, conn26_1.5
/G: Q0.2 (G), R6.1, R7.2
ADIR: U1.14 (D13), U5.8 (DIR)
ASTEP: RstpA1.1, U1.12 (D11), U5.7 (STEP), conn26_0.13
B_led: U1.20 (A2), conn26_0.23
B_sig: U1.17 (A5), conn26_0.15
D: Pump1.2, Q0.1 (D), Rp1.1
DC: U1.1 (D0/RX), conn26_1.6
EN: R5.2, U1.9 (D8), U2.1 (EN), U3.1 (EN), U4.1 (EN), U5.1 (EN)
GND: MP1584EN_DC-DC1.1, MP1584EN_DC-DC1.2, MP1584EN_DC-DC1.7, MP1584EN_DC-DC1.8, Pled1.1 (K), Q0.3 (S), R1.2, R2.2, R3.2, R4.2, R6.2, SW1.1, SW1.2, U1.15 (GND), U1.24 (GND), U1.25 (GND), U2.9 (GND), U3.9 (GND), U4.9 (GND), U5.9 (GND), V_led1.1 (K), Vled1.1 (K), conn26_0.2, conn26_0.4, conn26_0.6, conn26_0.8, conn26_0.10, conn26_0.12, conn26_0.14, conn26_0.16, conn26_0.18, conn26_0.20, conn26_0.22, conn26_0.24, conn26_0.26, conn26_1.2, conn26_1.8, l_pwr1.1, ledA1.1 (K), ledX1.1 (K), ledY1.1 (K), ledZ1.1 (K), pi_5V1.1
GNDA: C1.2, C2.2, C3.2, C4.2, P8.2, P8.3, U2.15 (GND), U3.15 (GND), U4.15 (GND), U5.15 (GND)
unnamed: MSA1.2, R4.1, U5.2 (MS1)
unnamed: MSA1.4, U5.3 (MS2)
unnamed: MSA1.6, U5.4 (MS3)
unnamed: MSX1.2, R1.1, U2.2 (MS1)
unnamed: MSX1.4, U2.3 (MS2)
unnamed: MSX1.6, U2.4 (MS3)
unnamed: MSY1.2, R2.1, U3.2 (MS1)
unnamed: MSY1.4, U3.3 (MS2)
unnamed: MSY1.6, U3.4 (MS3)
unnamed: MSZ1.2, R3.1, U4.2 (MS1)
unnamed: MSZ1.4, U4.3 (MS2)
unnamed: MSZ1.6, U4.4 (MS3)
unnamed: Pled1.2 (A), Rp1.2
unnamed: Rpwr1.2, Vled1.2 (A)
unnamed: Rpwr_1.2, V_led1.2 (A)
unnamed: RstpA1.2, ledA1.2 (A)
unnamed: RstpX1.2, ledX1.2 (A)
unnamed: RstpY1.2, ledY1.2 (A)
unnamed: RstpZ1.2, ledZ1.2 (A)
unnamed: U2.5 (RST), U2.6 (SLP)
unnamed: U3.5 (RST), U3.6 (SLP)
unnamed: U4.5 (RST), U4.6 (SLP)
unnamed: U5.5 (RST), U5.6 (SLP)
O_led: U1.22 (A0), conn26_0.19
O_sig: U1.21 (A1), conn26_0.21
RESET: SW1.3, SW1.4, U1.28 (RESET), conn26_0.25
VIN: C1.1, C2.1, C3.1, C4.1, MP1584EN_DC-DC1.3, MP1584EN_DC-DC1.4, P10.1, Pump1.1, Rpwr1.1, U2.16 (VMOT), U3.16 (VMOT), U4.16 (VMOT), U5.16 (VMOT), l_pwr1.2
VIN_: P8.1, P10.2, Rpwr_1.1
XDIR: U1.6 (D5), U2.8 (DIR)
XLIMIT: U1.10 (D9), conn26_0.9, conn26_0.11
XSTEP: RstpX1.1, U1.3 (D2), U2.7 (STEP)
YDIR: U1.7 (D6), U3.8 (DIR)
YLIMIT: U1.11 (D10), conn26_0.5, conn26_0.7
YSTEP: RstpY1.1, U1.4 (D3), U3.7 (STEP)
ZDIR: U1.8 (D7), U4.8 (DIR)
ZLIMIT: U1.13 (D12), conn26_0.1, conn26_0.3
ZSTEP: RstpZ1.1, U1.5 (D4), U4.7 (STEP)
_SCL_: U1.30 (_SCL_), conn26_1.3
_SDA_: U1.29 (_SDA_), conn26_1.4
a1A: U5.12 (1A), conn26_1.21
a1B: U5.11 (1B), conn26_1.23
a2A: U5.13 (2A), conn26_1.19
a2B: U5.14 (2B), conn26_1.17
pump_ctrl: R7.1, U1.18 (A4)
res: U1.2 (D1/TX), conn26_1.7
up_light: U1.19 (A3), conn26_0.17
x1A: U2.12 (1A), conn26_1.14
x1B: U2.11 (1B), conn26_1.16
x2A: U2.13 (2A), conn26_1.12
x2B: U2.14 (2B), conn26_1.10
y1A: U3.12 (1A), conn26_1.13
y1B: U3.11 (1B), conn26_1.15
y2A: U3.13 (2A), conn26_1.11
y2B: U3.14 (2B), conn26_1.9
z1A: U4.12 (1A), conn26_1.22
z1B: U4.11 (1B), conn26_1.24
z2A: U4.13 (2A), conn26_1.20
z2B: U4.14 (2B), conn26_1.18

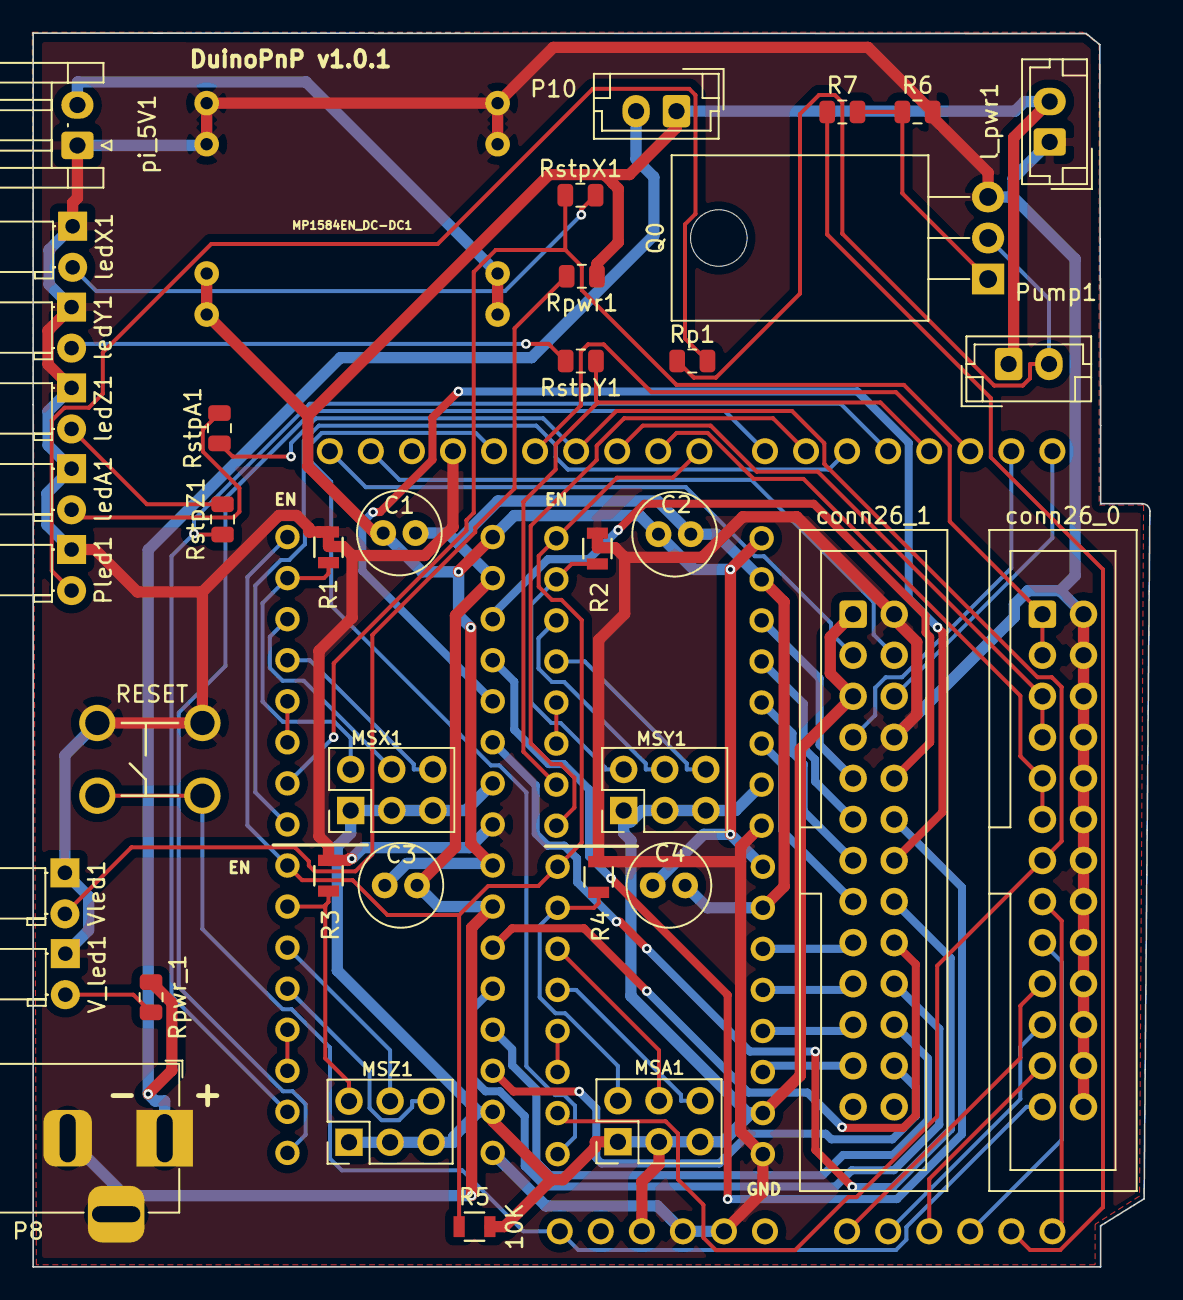
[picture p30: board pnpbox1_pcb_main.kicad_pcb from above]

Board: 2 copper layers, 69.1 x 76.3 mm, 44 parts (0 on the bottom side), 70 nets.

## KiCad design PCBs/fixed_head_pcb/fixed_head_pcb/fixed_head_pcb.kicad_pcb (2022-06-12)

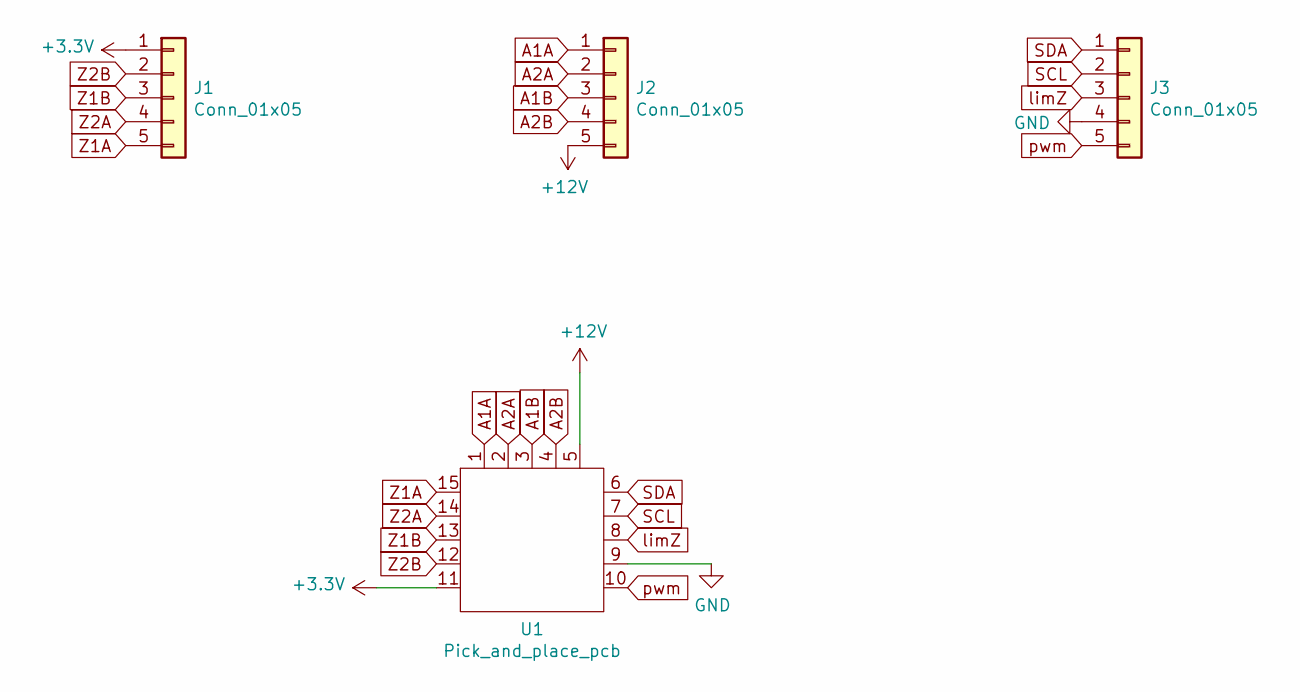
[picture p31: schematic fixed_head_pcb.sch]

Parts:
J1, J2, J3: Conn_01x05; JST_EH_B5B-EH-A_1x05_P2.50mm_Vertical
U1: Pick_and_place_pcb; fixed_head_PCB_v1.0

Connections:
+3V3: J1.1, U1.11
+12V: J2.5, U1.5
A1A: J2.1, U1.1
A1B: J2.3, U1.3
A2A: J2.2, U1.2
A2B: J2.4, U1.4
GND: J3.4, U1.9
SCL: J3.2, U1.7
SDA: J3.1, U1.6
Z1A: J1.5, U1.15
Z1B: J1.3, U1.13
Z2A: J1.4, U1.14
Z2B: J1.2, U1.12
limZ: J3.3, U1.8
pwm: J3.5, U1.10

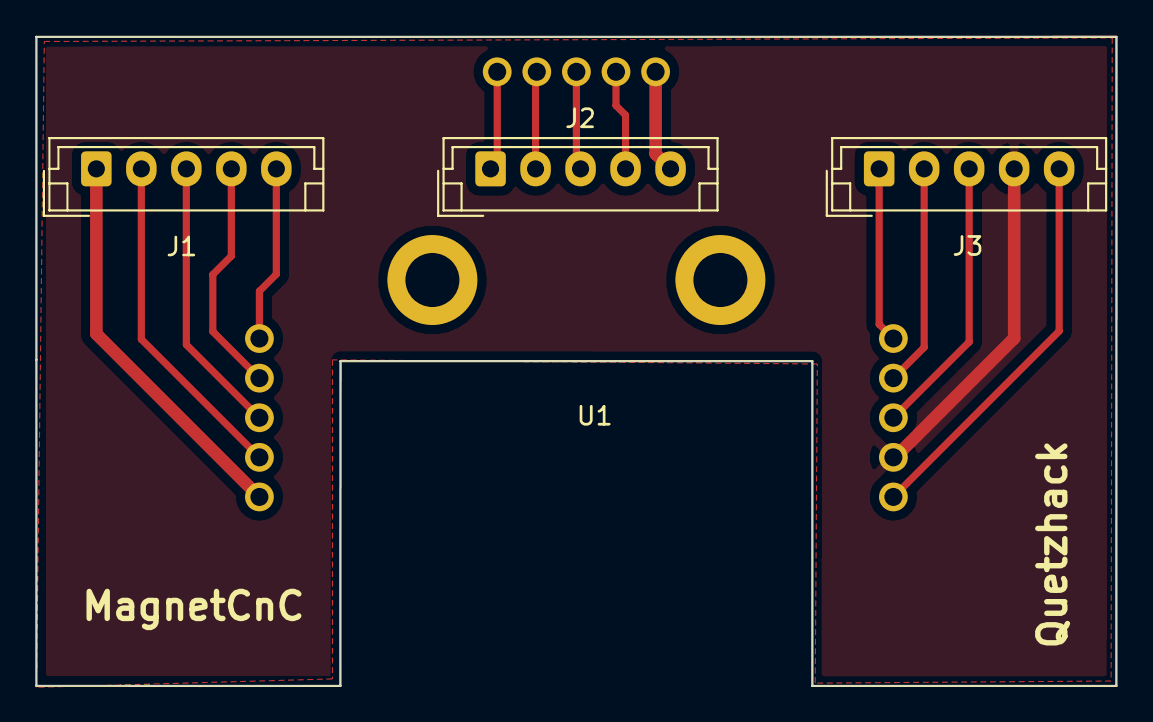
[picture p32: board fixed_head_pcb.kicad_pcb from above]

Board: 2 copper layers, 60.0 x 36.1 mm, 4 parts (0 on the bottom side), 15 nets.

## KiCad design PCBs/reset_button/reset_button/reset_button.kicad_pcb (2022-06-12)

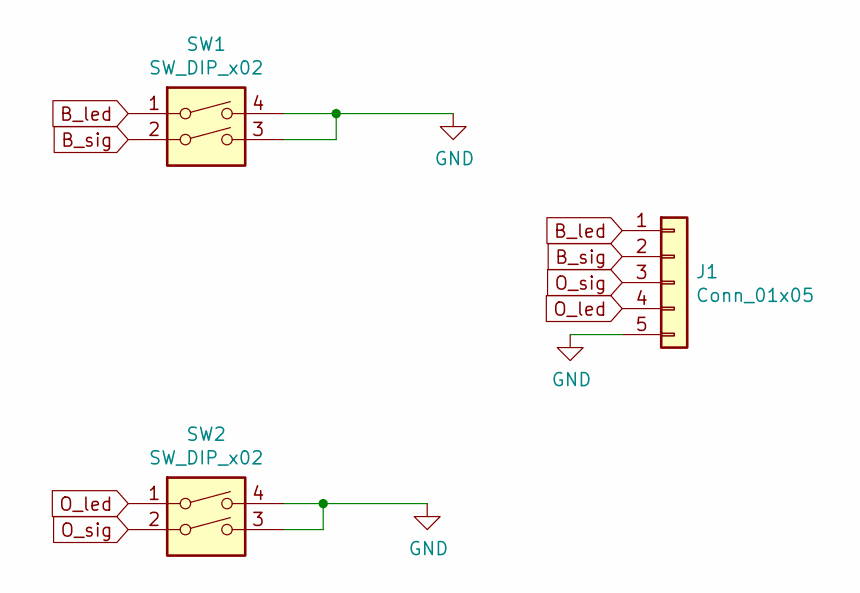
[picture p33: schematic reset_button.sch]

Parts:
J1: Conn_01x05; JST_EH_B5B-EH-A_1x05_P2.50mm_Vertical
SW1, SW2: SW_DIP_x02; reset_button

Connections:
B_led: J1.1, SW1.1
B_sig: J1.2, SW1.2
GND: J1.5, SW1.3, SW1.4, SW2.3, SW2.4
O_led: J1.4, SW2.1
O_sig: J1.3, SW2.2

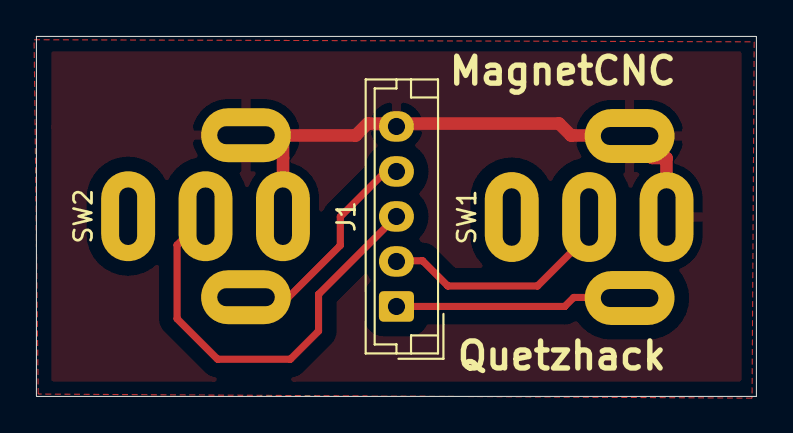
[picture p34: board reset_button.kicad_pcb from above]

Board: 2 copper layers, 40.0 x 20.0 mm, 3 parts (0 on the bottom side), 5 nets.

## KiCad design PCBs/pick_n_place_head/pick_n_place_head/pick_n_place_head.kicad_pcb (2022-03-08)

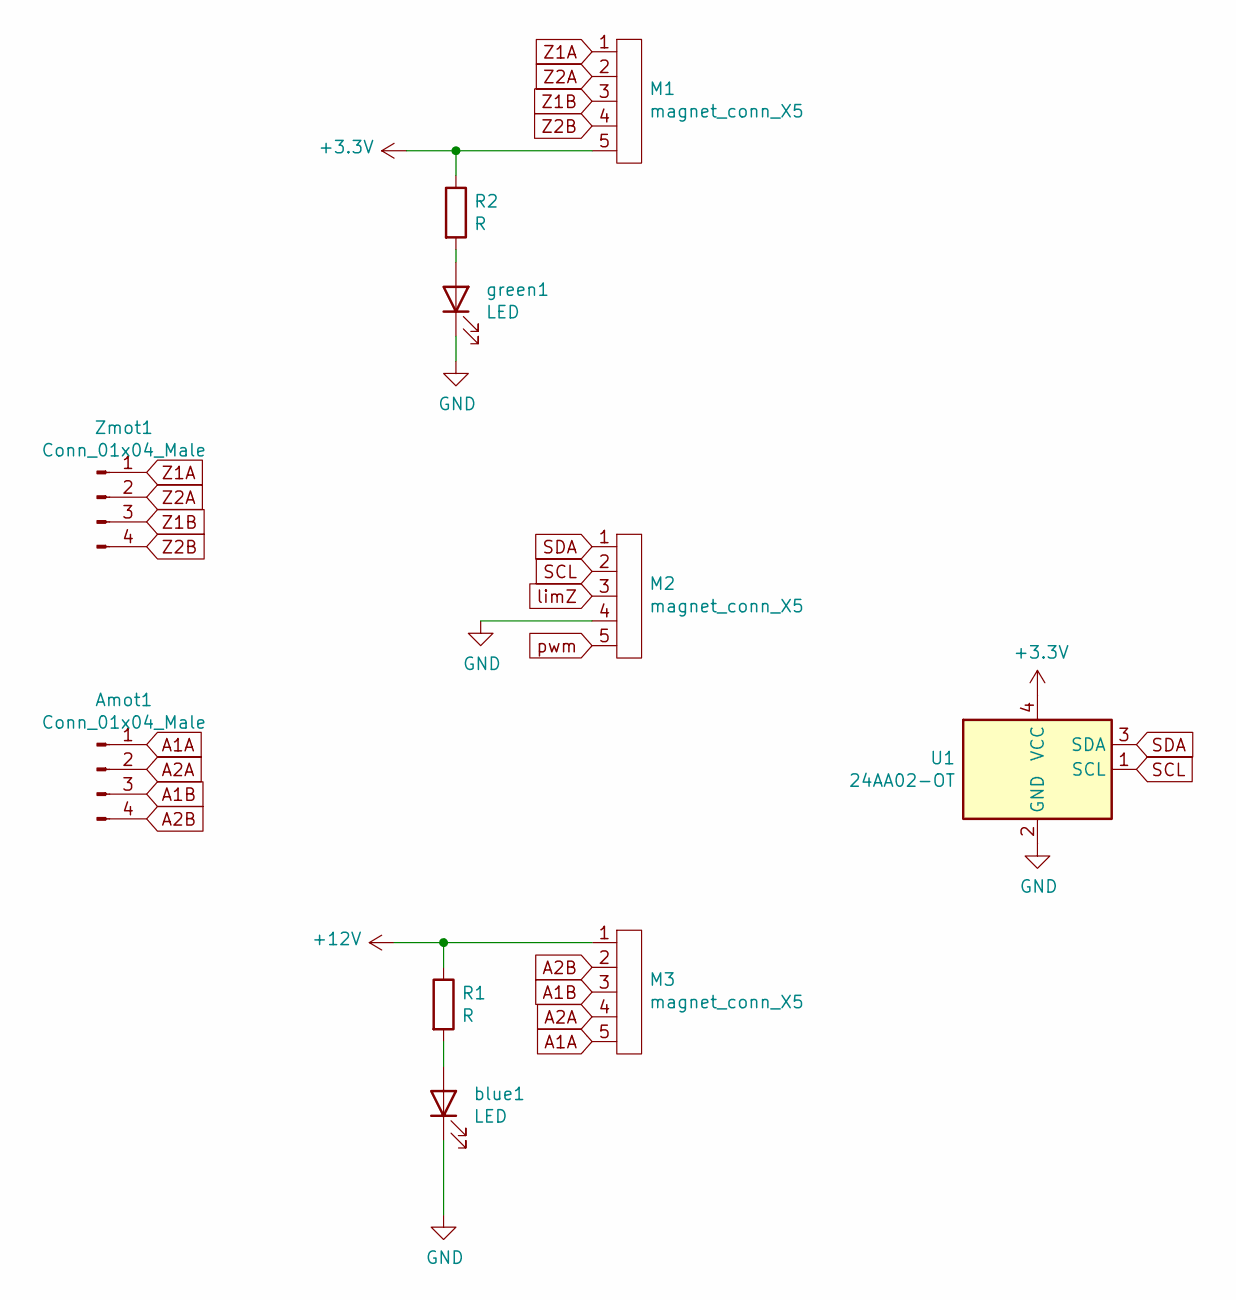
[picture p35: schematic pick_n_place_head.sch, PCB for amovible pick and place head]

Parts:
Amot1: Conn_01x04_Male; PinHeader_1x04_P2.54mm_Vertical
M1, M2, M3: magnet_conn_X5
R1, R2: R; R_0805_2012Metric
U1: 24AA02-OT; SOT-23-5
Zmot1: Conn_01x04_Male; PinHeader_1x04_P2.54mm_Vertical
blue1: LED; LED_1206_3216Metric
green1: LED; LED_1206_3216Metric

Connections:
+3V3: M1.5, R2.1, U1.4 (VCC)
+12V: M3.1, R1.1
A1A: Amot1.1, M3.5
A1B: Amot1.3, M3.3
A2A: Amot1.2, M3.4
A2B: Amot1.4, M3.2
GND: M2.4, U1.2 (GND), blue1.1 (K), green1.1 (K)
unnamed: R1.2, blue1.2 (A)
unnamed: R2.2, green1.2 (A)
SCL: M2.2, U1.1 (SCL)
SDA: M2.1, U1.3 (SDA)
Z1A: M1.1, Zmot1.1
Z1B: M1.3, Zmot1.3
Z2A: M1.2, Zmot1.2
Z2B: M1.4, Zmot1.4
limZ: M2.3
pwm: M2.5

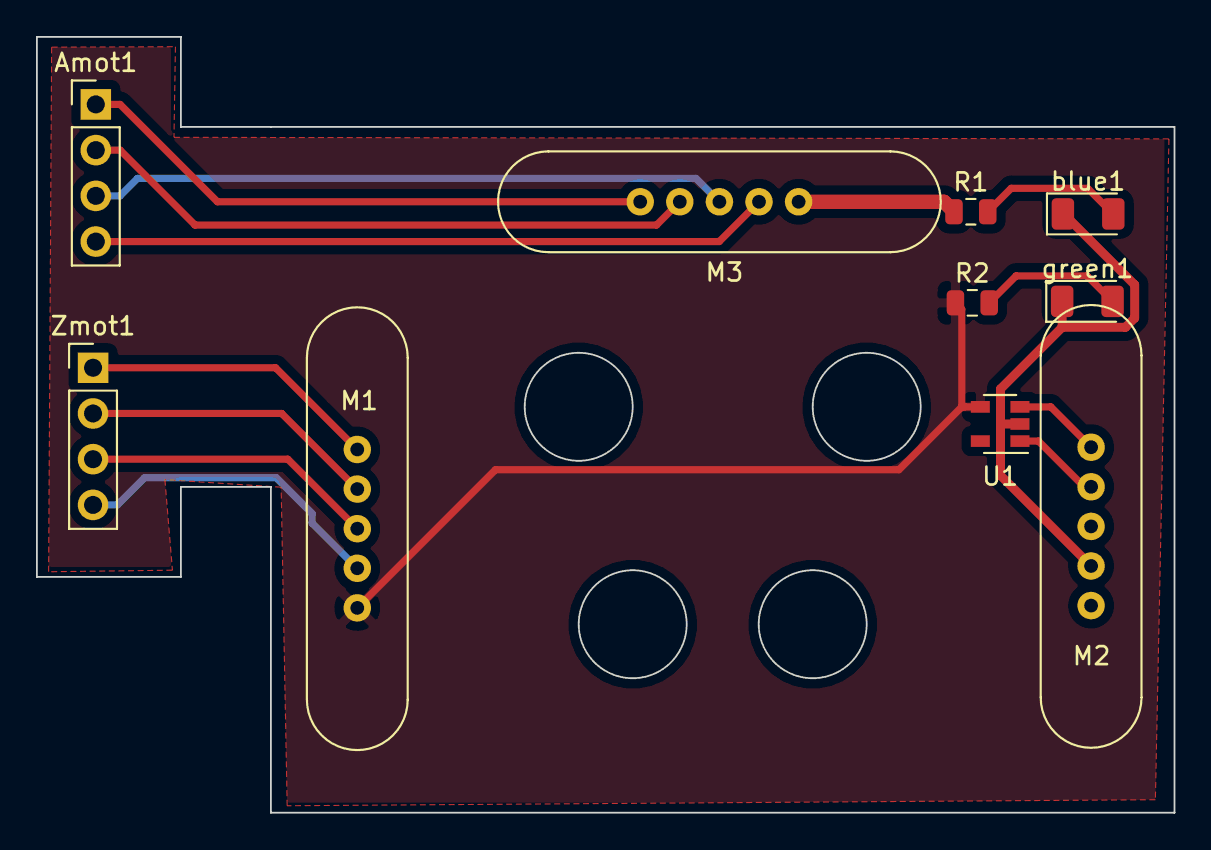
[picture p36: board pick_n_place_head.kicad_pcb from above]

Board: 2 copper layers, 63.2 x 43.1 mm, 10 parts (0 on the bottom side), 15 nets.

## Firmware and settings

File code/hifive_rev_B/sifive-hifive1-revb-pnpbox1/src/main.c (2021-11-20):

#include <stdio.h>
#include <stdint.h>
#include <string.h>
#include "uart.h"
#include "cpu.h"
#include "spi.h"
#include "led.h"
#include <metal/gpio.h>


#define DELAY           20000000
#define BAUDRATE_115200 115200
#define SPICLOCK_80KHZ  80000
#define STR_LEN         1024
#define BUF_LEN         4096
#ifdef __ICCRISCV__
#define fflush(a)
#endif

#define stepPerRevolution 200

static const uint32_t interactive = 1; // Set to 0 to use hardcoded SSID and pwd
static char cmd_[STR_LEN];
struct metal_gpio* gpio_;

int main(void)
{


    cpu_clock_init();
    uart_init(BAUDRATE_115200);

    printf("---- Project about porting the grbl arduino code on HiFive1 Rev B   --------\r\n");
    printf("* UART: 115200 bps\r\n");
    printf("* CPU: 320 MHz\r\n");

    //gpio_ = metal_gpio_get_device(0);
    //metal_gpio_enable_pinmux(gpio_,19,0);
   // metal_gpio_enable_output(gpio_,19);
    //IOF_DISABLE(LED_GREEN);
    //IOF_DISABLE(LED_BLUE);
    gpio_enable(LED_GREEN); //stepPin
    gpio_enable(LED_BLUE); //dirPin
    gpio_enable(LED_RED);
    LED_on(LED_BLUE);
    while(1) {

     for(int i=0; i < 2*stepPerRevolution;i++) {
      //gpio_set_val(LED_GREEN);
      LED_toggle(LED_GREEN);
      //metal_gpio_toggle_pin(gpio_, 19);
      //metal_gpio_set_pin(gpio_,19,1);
    	  delay(20000);
    }
    delay(100000000);
    LED_toggle(LED_RED);
    }
    /*
    while(1) {
    if (interactive) {
        get_cmd(cmd_, STR_LEN);
    }
  }*/


}

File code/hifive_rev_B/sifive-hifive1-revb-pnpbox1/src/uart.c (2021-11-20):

#include <string.h>
#include <stdint.h>
#include <stdio.h>
#include "uart.h"
#include "cpu.h"

#define IOF_EN          *(volatile uint32_t*)0x10012038
#define IOF_SEL         *(volatile uint32_t*)0x1001203C

#define UART0_TXDATA    *(volatile uint32_t*)0x10013000
#define UART0_RXDATA    *(volatile uint32_t*)0x10013004
#define UART0_TXCTRL    *(volatile uint32_t*)0x10013008
#define UART0_RXCTRL    *(volatile uint32_t*)0x1001300C
#define UART0_DIV       *(volatile uint32_t*)0x10013018

#define UART_TXEN_I     0U
#define UART_RXEN_I     0U

#define BIT_MASK(bit) (1UL<<(bit))
#define UART0_RX    16
#define UART0_TX    17
#define IOF_UART_ENABLE (BIT_MASK(UART0_RX) | BIT_MASK(UART0_TX))

void uart_init(uint32_t baudrate)
{
    // Select HW I/O function 0 (IOF0) for all pins.
    // IOF0 means UART mode for GPIO pins 16-17.
    IOF_SEL = 0;

    IOF_EN |= IOF_UART_ENABLE;
    UART0_TXCTRL = 0;
    UART0_RXCTRL = 0;
    UART0_DIV = cpu_freq() / baudrate - 1UL;
    UART0_TXCTRL = BIT_MASK(UART_TXEN_I);
    UART0_RXCTRL = BIT_MASK(UART_RXEN_I);
}

void uart_send(const char *str_p)
{
    uint32_t len = strlen(str_p);
    for (uint32_t i=0; i < len; i++)
    {
        while (UART0_TXDATA > 0xFF) {} // full bit set, wait
        UART0_TXDATA = str_p[i] & 0xFFU;
    }
}

int uart_putchar(char c)
{
    while (UART0_TXDATA > 0xFF) {} // full bit set, wait
    UART0_TXDATA = c & 0xFFU;
    return 0;
}

int uart_getchar(void)
{
    uint32_t c;

    while (1) {
        c = UART0_RXDATA;   // Read the RX register EXACTLY once
        if (c <= 0xFF) {    // Empty bit was not set, which means DATA is valid
            return c;
        }
    } // Loop as long empty bit is set
}




//----------------------------------------------------------------------
// A gets function that stops for \n AND \r (good with PUTTY)
//----------------------------------------------------------------------
char *tty_gets(char *str_p, uint32_t size)
{
    uint32_t i;
    int32_t c;

    for (i = 0; i < size; i++) {
        c = uart_getchar();
        uart_putchar(c);

        if (c == '\n' || c == '\r') {
            str_p[i] = '\0';
            return str_p;
        } else if (c > 0xFF) {
            return NULL;
        }
        str_p[i] = c;

    }

    if (size > 0) {
        str_p[size-1] = '\0';
    }
    return str_p;
}



//----------------------------------------------------------------------
// Hack to read ssid and pwd from terminal
//----------------------------------------------------------------------
void get_cmd(char *cmd, uint32_t size)
{

    printf("Enter command: ");
    fflush(stdout);
    while (NULL == tty_gets(cmd, size)) {}
    printf("\r\n");

}

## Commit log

2021-09-22 enable M7 command for pump control
2021-09-26 use 'abort' GPIO for orange button led
2021-10-03 add freecad and kicad
    [adv_support_left2.obj, ajust_drag_chain.obj, ajust_drag_chain_pilone.FCStd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]
2021-10-03 modified directory structure and change arduino path for lib and main
2021-10-03 disable Z homing
2021-10-05 program homing after reset or boot
2021-10-10 remove homing after reset and add openpnp cfg
2021-10-22 add jack barrel for power supply in kicad
    [sb-cnc-shield.kicad_pcb, sb-cnc-shield.sch]
2021-10-22 add jack barrel for power supply in kicad, correction
    [sb-cnc-shield.csv, sb-cnc-shield.kicad_pcb, sb-cnc-shield.sch]
2021-10-22 modify jack barrel position for power supply in kicad
    [sb-cnc-shield.kicad_pcb]
2021-10-22 modify the 4 capacitors foorprint and rotate MS1/2/3 connector
    [sb-cnc-shield.kicad_pcb]
2021-10-22 modify name
    [sb-cnc-shield.kicad_pcb]
2021-10-22 connect GNDs and connect the e-stop for reset
    [sb-cnc-shield.kicad_pcb, sb-cnc-shield.sch]
2021-10-22 rename directory to PCBs directory
    [sb-cnc-shield.csv, sb-cnc-shield.kicad_pcb, sb-cnc-shield.sch]
2021-10-22 modify name PCBs
    [sb-cnc-shield.kicad_pcb, sb-cnc-shield.sch]
2021-10-22 add _SDC_ _SCL_ for hi five rev b board
    [sb-cnc-shield.kicad_pcb]
2021-10-22 add power button, lenghten pcb
    [sb-cnc-shield.kicad_pcb, sb-cnc-shield.sch]
2021-10-24 add pump management circuit, I2C JST conn for display, JST power switch
    [sb-cnc-shield.kicad_pcb, sb-cnc-shield.sch]
2021-10-25 add voltage regulator shield for 5V rpi
    [sb-cnc-shield.kicad_pcb, sb-cnc-shield.sch]
2021-10-31 modify kicad and create gerbers then ordering PCBs on JLPCB
    [sb-cnc-shield-B_Cu.gbl, sb-cnc-shield-B_Mask.gbs, sb-cnc-shield-B_Paste.gbp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]
2021-11-01 remove README in PCBs
2021-11-17 add images
    [sb-cnc-shield.kicad_pcb]
2021-11-17 add readme for programming stepper motor, basis
2021-11-17 add kicad image
    [sb-cnc-shield.kicad_pcb]
2021-11-24 modify hifive1_revb devicetree to adescribe a little flash partition
    [sb-cnc-shield-B_Cu.gbl, sb-cnc-shield-B_Mask.gbs, sb-cnc-shield-B_Paste.gbp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]
2021-12-04 correct z1A pinoutgit add .!
    [left_case_2.FCStd, pnp_case_left_2.obj, pnp_case_right_2.obj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]
2021-12-04 add DB25 pinout
    [sb-cnc-shield.dsn, sb-cnc-shield.kicad_pcb, sb-cnc-shield.sch]
2021-12-05 pinout modify
    [sb-cnc-shield.kicad_pcb, sb-cnc-shield.sch]
2021-12-05 add 3Dview of PCB
    [sb-cnc-shield-B_Cu.gbl, sb-cnc-shield-B_Mask.gbs, sb-cnc-shield-B_Paste.gbp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]
2021-12-10 modify arduino code to switch D12 adn D11 digital pin (Astep to Zlim)
2022-01-20 add main-head-mobile freecad
    [belt_general.obj, for_fixing_drag_chain_on_head.FCStd, for_fixing_drag_chain_on_head.obj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]
2022-01-29 update freecad design
    [magnet_support_fixed_1.01.FCStd, magnet_support_main_fixed_1.01.obj, main_head.FCStd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]
2022-03-08 modify kicad and freecad
    [fixed_head_pcb.dsn, fixed_head_pcb.kicad_pcb, main_head_PnP_v1.01.FCStd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]
2022-03-26 add acrylic cut and other freecad design
    [acrylic.kicad_pcb, acrylic.sch, acrylic_head_pnp.FCStd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]
